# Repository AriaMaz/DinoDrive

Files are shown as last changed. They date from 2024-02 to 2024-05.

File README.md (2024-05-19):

# DinoDrive

<a href="https://code.engineering.queensu.ca/mren303_w2024/section003_group10_dinodrive/-/blob/main/README.md">
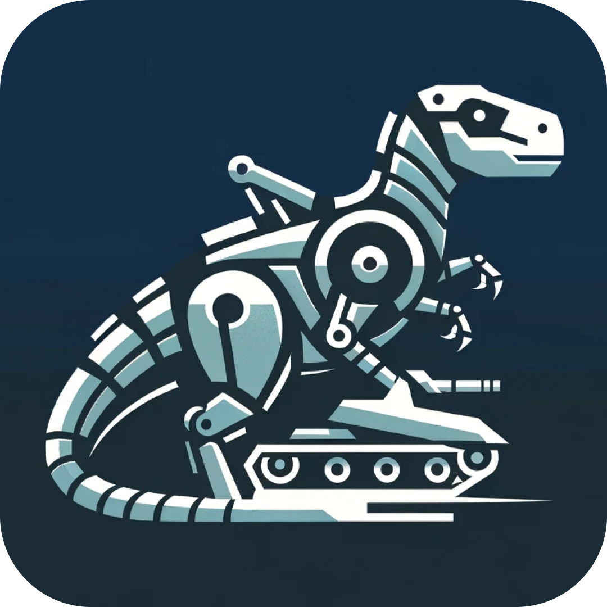
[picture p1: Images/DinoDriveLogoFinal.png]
    
</a>

</a>

Aria Maz <br>
Daniel Dubinko
<p><p>

Semi-autonomous robotic system developed for a competitive arena of navigation and object manipulation. <br>
– The robot operates in autonomous line following and manual remote controller modes.
<!-- <br> -->

<details>

<summary><h4>Setup</h4></summary>
To use this model, it is recommended to run the following command in your terminal based on your respective opperating system below to create a virtual environment and download the required package managerss, interpreters, and libraries.

#### MacOS

```html
<p>/bin/bash -c "$(curl -fsSL https://raw.githubusercontent.com/Homebrew/install/HEAD/install.sh)" && brew install python3 arduino && mkdir DinoDriveProject && cd DinoDriveProject && python3 -m venv DinoDriveEnv && source DinoDriveEnv/bin/activate && pip install opencv-python pyserial</p>
```

#### Windows

```html
<p>mkdir DinoDriveProject; cd DinoDriveProject; python -m venv DinoDriveEnv; .\DinoDriveEnv\Scripts\Activate; pip install opencv-python pyserial; choco install arduino</p>
```

#### Linux

```html
<p>sudo apt update && sudo apt install python3-venv python3-pip arduino && mkdir DinoDriveProject && cd DinoDriveProject && python3 -m venv DinoDriveEnv && source DinoDriveEnv/bin/activate && pip install opencv-python pyserial</p>
```
  </details>

<h3 align="center">Click on the image below to download the Report for this project</h3>
<div align="center">
    <a href="https://raw.githubusercontent.com/AriaMaz/DinoDrive/d2ab13fa74b5031a392671a74e04fc58c0d62a4a/MREN303FinalReport.pdf" download>
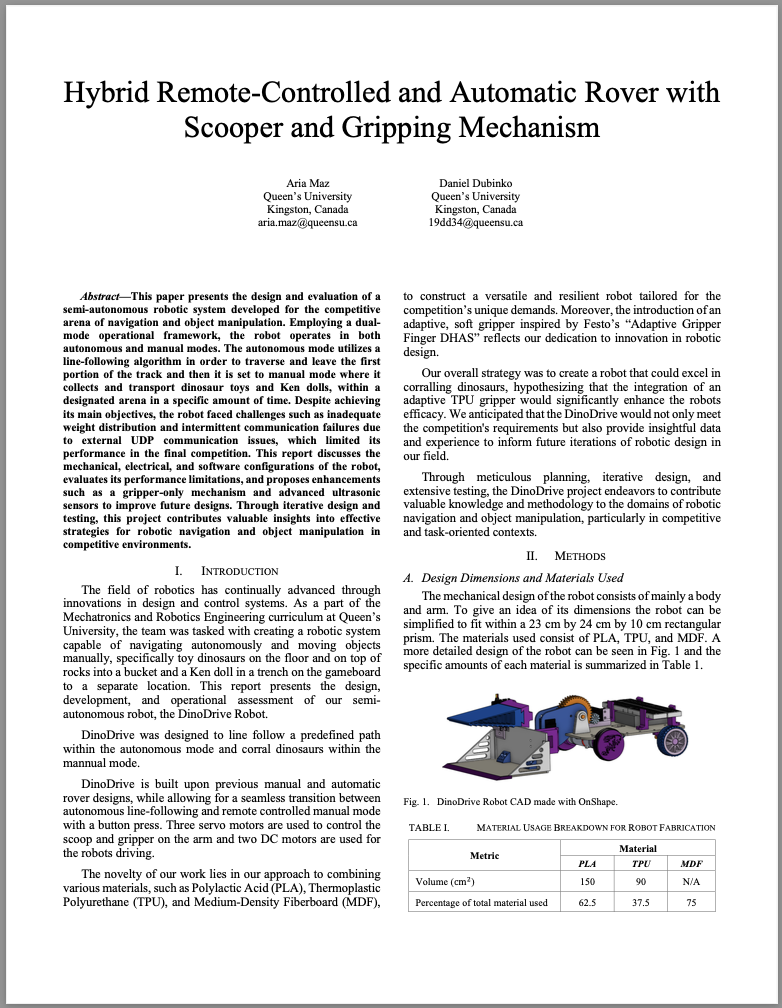
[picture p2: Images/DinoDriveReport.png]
PDF Preview
        
    </a>
</div>

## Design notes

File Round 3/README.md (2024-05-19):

## Goals for Round 3

1. Complete Round 3 Documentation
2. Design Electrical Schematic
3. Create Power Budget to ensure there suffucient power to power all the sensors
4. 3D Print and Assemble Mechanical Module
5. Scrum Planning for Round 3
6. Team Assessment and Peer Feedback
7. Manufacturing and Assembling Components 
8. Continously Keep Track of 3D Printed Volume

## DinoDrive Team Goals

1. Determine the amount of material needed to wrap the wheels in the rubber string
2. Create full proof code to control the servo motors and DC motors with the controller
3. Print the front wheels and laser cut the back wheels
4. CAD Model the line sensor and ultrasonic sensor mounts

## Backlog Items

1. Complete the CAD model for the base and main arm
2. Create gears for operating the arm and scoop
3. CAD the grippers for the front of the scoop

## Tasks to Reach Each Goal and Team Member Responsible
### Design Electrical Schematic
- **Tasks:**
  - Identify all components requiring electrical connections
  - Create a list of electrical specifications for each component
  - Plan the layout of the electrical schematic
  - Use appropriate software to design the electrical schematic

- **Team Members:**
  - Aria Maz

### Create Power Budget to ensure there is sufficient power to power all the sensors
- **Tasks:**
  - Determine the power requirements for each component
  - Calculate the total power consumption
  - Compare the total power consumption with the given battery pack

- **Team Member:**
  - Aria Maz

### 3D Print and Assemble Mechanical Module
- **Tasks:**
  - Review and finalize the 3D models for mechanical components
  - Assemble the printed components into the mechanical module
  - Inspect the assembled module for functionality and structural integrity

### Scrum Planning
- **Tasks:**
  - Review the progress of the project from the previous round
  - Identify and prioritize tasks for the upcoming round
  - Assign responsibilities to team members
  - Conduct a planning meeting with the Scrum team

- **Team Members:**
  - Daniel Dubinko
  - Aria Maz

### Team Assessment and Peer Feedback
- **Tasks:**
  - Dicuss goal progression and healthy, fact-driven conflict and ways to imporve them. 
  - Dicuss team commincation and focus and how to impove them
  - Sumarize findings in the correct file

- **Team Members:**
  - Daniel Dubinko
  - Aria Maz

###  Manufacturing and Assembling Components
- **Tasks:**
  - Convert 3D CAD models into STL files for 3D printing
  - Track the 3D print volume
  - Convert 3D CAD models into SVG files for laser cutting

- **Team Members:**
  - Daniel Dubinko

### Determine the Amount of Material Needed to Wrap the Wheels in the Rubber String
- **Tasks:**
  - Measure the circumference of each wheel
  - Calculate the required length of rubber string for each wheel
  - Cut the rubber string

- **Team Member:**
  - Daniel Dubinko

### Create foolproof code to control the servo motors and DC motors with the controller
- **Tasks:**
  - Develop a control algorithm for servo motors and DC motors
  - Write and test the code for motor control
  - Implement error handling and fail-safe mechanisms in the code
  - Document the code for future reference

- **Team Member:**
  - Aria Maz

### Create Gears for Operating the Arm and Scoop
- **Tasks:**
  - Design gears based on the required specifications.
  - 3D print gears for manufacturing.
  - Assemble gears.

- **Team Member:**
  - Daniel Dubinko

### CAD the Grippers for the Front of the Scoop
- **Tasks:**
  - Utilize CAD software (Onshape) to design grippers for the scoop.
  - Ensure the gripper design is compatible with the overall system.
  - CAD grip attachments to the servo.

- **Team Member:**
  - Daniel Dubinko

### Complete the CAD Model for the Base and Main Arm
- **Tasks:**
  - Utilize CAD software to create a detailed model of the base and main arm.
  - Ensure accuracy and compatibility with other components.
  - Review and finalize the CAD model.

- **Team Member:**
  - Daniel Dubinko

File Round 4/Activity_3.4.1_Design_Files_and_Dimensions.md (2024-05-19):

# Design Files Round 4
The design files can be found in **STL Files** Folder, and the **Laser Cutting Files** Folder, including dimensions of every part printed or cut. 

The design files include the STL Files for 3D printing, the Laser cutting files for all the MDF components and Measurements for all the components. 

**Total**: 245806 mm^3
**PLA Parts Printed**: 100,000 mm^3
**TPU Parts Printed**: 0 mm^3

**Material Left**: 145806 mm^3

*specific part volumes will be given in the later dates

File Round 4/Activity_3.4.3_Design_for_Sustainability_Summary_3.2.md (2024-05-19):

# Design For Sustainability

After discussing the various financial and environmental considerations in the fabrication and deployment of the robotic system within our team, we came to the conclusion that some of the approaches for sustainability relate to our current design process within our robots, such as using our code to achieve energy efficiency. 

Some approaches we take relate to our robot design, such as prioritizing more sustainable filaments and rechargeable batteries. We plan to add some conditions so that specific devices on the robot run only when needed so that the standby power consumption is significantly lower than when the robot is running all its sensors and actuators.

https://all3dp.com/2/best-sustainable-eco-friendly-biodegradable-3d-printer-filaments/

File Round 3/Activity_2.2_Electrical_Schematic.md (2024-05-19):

# Electrical Schematic

electrical subsystem
<strong>Figure 1:</strong> Physical electrical subsystem for DinoDrive robot.

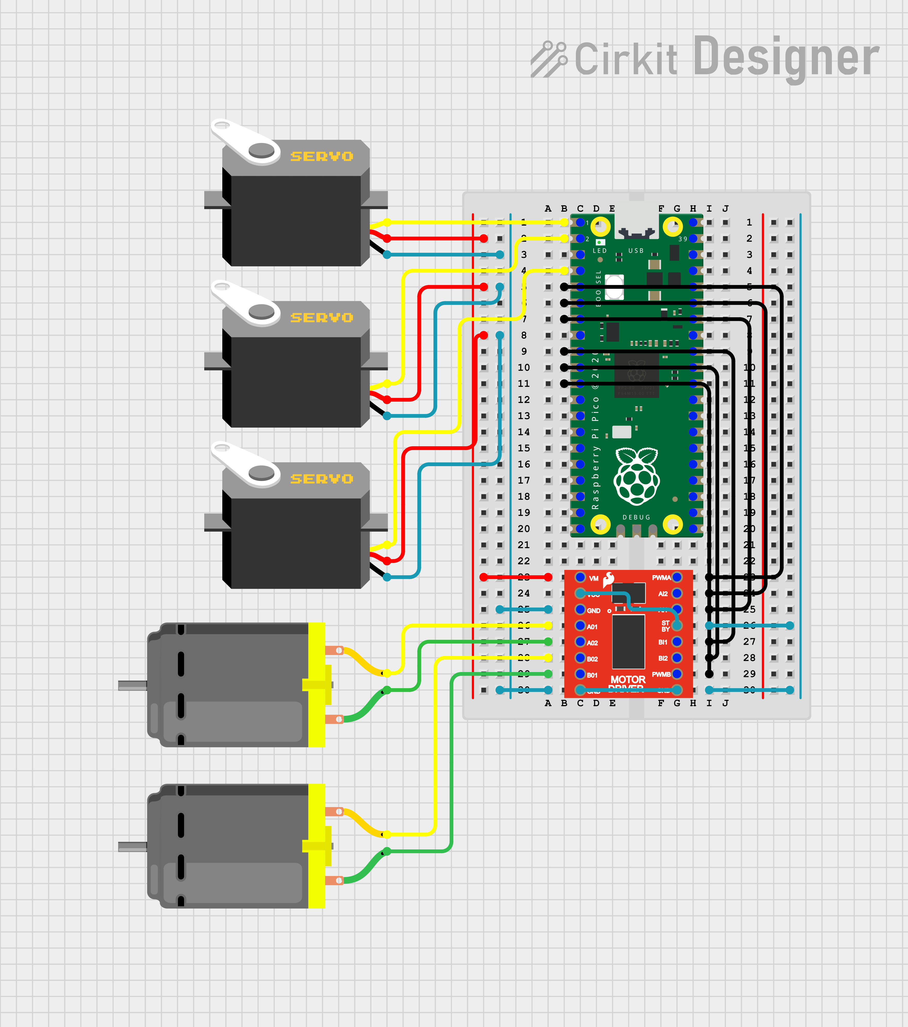
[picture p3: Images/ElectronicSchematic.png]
electrical schematic

<strong>Figure 2:</strong> Electrical schematic for DinoDrive robot.

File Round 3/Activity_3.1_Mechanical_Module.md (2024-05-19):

# Mechanical Module
## DC Motor and Back Wheel Attachment
The mechanical module chosen for display is the motor and wheel attachment to the main casing. The main casing and back wheel will be made out of carboard for display purposes until the laser cut parts can be obtained. 

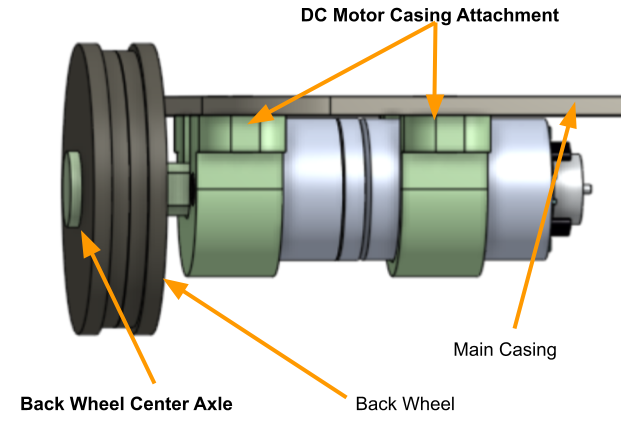
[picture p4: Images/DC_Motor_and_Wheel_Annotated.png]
<br>
**Figure 1:** DC Motor and Wheel attachment to the main casing.

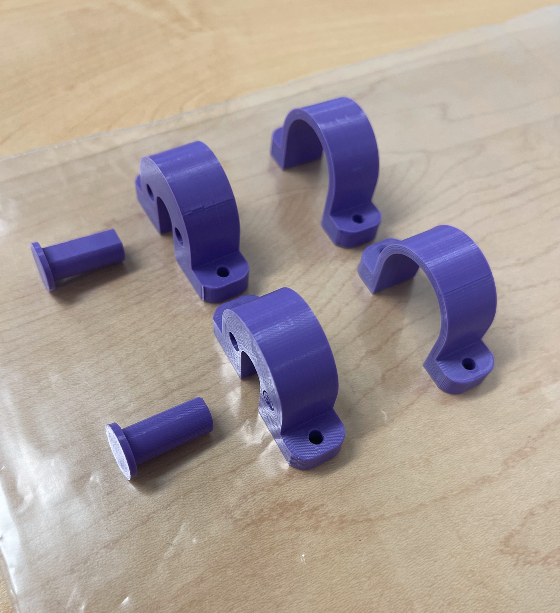
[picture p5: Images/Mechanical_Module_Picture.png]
<br>
**Figure 2:** DC Motor and Wheel 3D Printed Part.

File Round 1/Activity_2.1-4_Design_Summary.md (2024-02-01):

# Overarching Design Problem 

 1. Press the button, if the button press is not feasible then return to line following
    - leave the initial starting position using ultrasonic sensors by comparing the distance of all three sides. 
       - add PID to have precise movement during ultrasonic sensing
    - use the ultrasoninc sensors to align the robot in a way to press the button
    - set the grabbing/scooping portion of robot aligned at a predetermined height 
    - have back up line following code in case of any ultrasoninc sensor fails.
    
 2. Be able to enter through the door
    - realign the robot using the ultra sonic sensors and hard coded time to be able to enter through the door. 
    - since the ultrasonic sensors will be on the right, left, and front side have a max distance for the front side so the robot does not crash into the back wall

 3. Grab all the dinosaurs and place them into the black bucket
    - drive the robot using the Logitech Controller
    - knock off dinosaurs from the rocks or carefully grab them
    - grab each dinosaur separately and put them one by one into the bucket or push the dinosaurs together and scoop them into the bucket

 4. Ride up the ramp
    - ensure the robot does not bottom out when moving up the ramp
    - ensure the robot does not fall backwards comming up the ramp
    - ensure the robot does not get caught on the edge of the ramp

 5. Grab Ken 
    - grab or scoop Ken lighlty
    - raise him out of the ditch and continue down the ramp 
    - add fine steering control to make sure that Ken does not hit anything on any part of the journey

 6. Slowly take Ken to the helipad 
    - move fast enough to save time but slow enough to ensure the ride is smooth for Ken

# Constraints

1. 3D Printing Material
   - not exceeding the allowed amount

2. Time 
   - time is not being graded but a robot should not take too long to complete a task because that would be a waste of resources

3. Motors
   - only 3 servo motors and 2 DC motors are given. 

4. No Navigation Sensors Given (ex. LiDAR, Camera)
   - only ultrasonic sensors can be used for guidance 

5. Can Only Use Kit Materials
   - no other materials can be added 

6. Batteries Charge in 10 Hours so for iteration purposes the the back up batteries should always be charging

7. Batteries Output 4.8 volts when the DC motors require around 6V

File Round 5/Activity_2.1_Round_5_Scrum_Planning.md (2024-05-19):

# Goals for Round 5
1. Complete Round 5 Documentation
- Activity 2.1 (Aria Maz)
- Activity 2.3.3 (Aria Maz)
- Activity 4.3.1 (Daniel Dubinko)
- Activity 4.3.2 (Aria Maz)
2. Team Health Assessment and Peer Feedback
- Complete and reflect on feedback (Aria Maz and Daniel Dubinko)
3. Peer and Self-Assessment Surveys
- Conduct surveys and reflect on feedback (Aria Maz and Daniel Dubinko)
4. Update design files (Daniel Dubinko)
- Include a place to fit in the fail-safe line following the sensor on the CAD
5. Continuously Keep Track of 3D Printed Volume (Daniel Dubinko)
- Update [PLA](../STL_Files/PLA) and [TPU](../STL_Files/TPU) files in the [STL files](../STL_Files) (Daniel Dubinko).
6. Implement Autonomous mode
- Note: the main .ino script for running the robot should include code for the robot to execute during autonomous mode
- Milestones include demonstrating that the robot can run autonomously (Aria Maz).
  - Only need to demonstrate that we have programmed the robot to operate autonomously. Still, the algorithm does not have to be complete or successfully be able to exit the gameboard doors.
7. Prototype Testing
- Conduct tests on the gameboard and continuously iterate design (Aria Maz and Daniel Dubinko)

# DinoDrive Team Goals
1. Begin testing (Aria Maz and Daniel Dubinko)
- After finalizing the robot, begin practicing and  conduct a competition to see who is better at controlling the robot 
  - This will determine who will control it during the competition.

# Backlog Items
1. Update the CAD 
- Include ultrasonic Sensor Attachment and Line Sensor (Daniel Dubinko)

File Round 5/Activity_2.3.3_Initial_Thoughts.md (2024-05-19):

The team learnt that the scoop/claw to pick up Ken didn't generate enough torque to even move itself. Whilst the team had done rough back-of-the-envelope calculations for torque calculations the team failed to consider specifics such as the center of the mass of the claw with ken on it and its distance from the motors rotational Axis. The team decided to fix/improve the design by reducing the distance of the COM of the claw from the rotational axis of the servo motor and adding a 1:2 gear ratio since the full range of 180 degrees of motion is not necessary for our design and therefore can be sacrificed for the extra torque. Ideas generated to solve our low torque issue were inspired by the link below.

https://datamyte.com/blog/how-to-increase-motor-torque/#:~:text=By%20ensuring%20all%20moving%20parts,RPM%2C%20linearly%20increasing%20the%20torque.

However, the driving portion of the robot worked flawlessly, being able to complete sharp turns and climb the ramp with great traction and little to no skidding.

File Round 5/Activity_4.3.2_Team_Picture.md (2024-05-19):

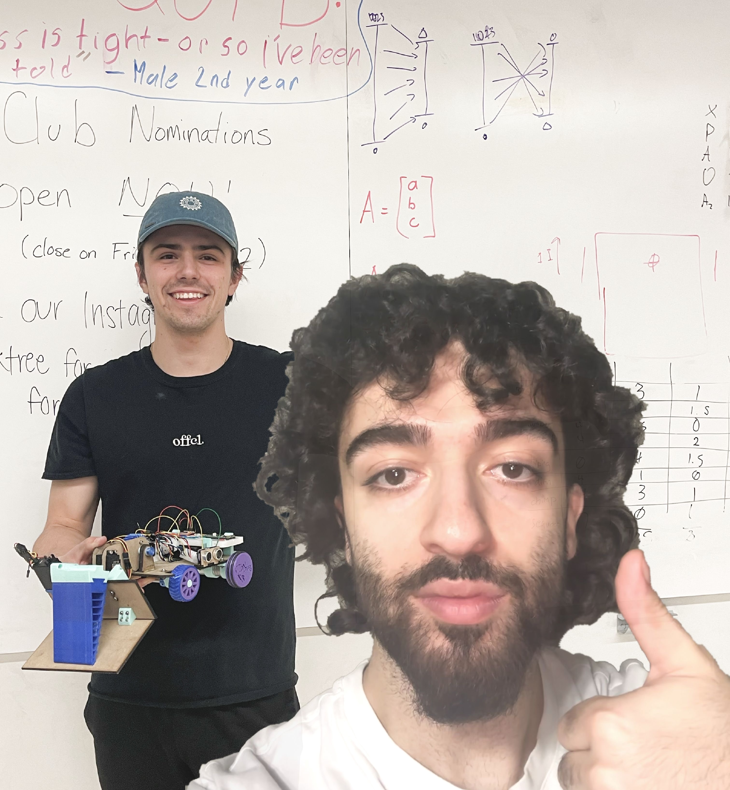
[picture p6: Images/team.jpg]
Team Photo
<br>
**Figure 1:** Picture of all team members (Aria Maz and Daniel Dubinko) with the current DinoDrive robot prototype.

We do consent to the use of our picture! :)

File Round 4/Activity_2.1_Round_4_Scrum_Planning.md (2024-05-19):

# Goals for Round 4

1. Complete Round 4 Documentation
2. Assemble Robot Chassis
3. Summarize Environmental Paragraph 
4. Scrum Planning for Round 3
6. Team Assessment and Peer Feedback Summary and 
7. Manufacturing and Assembling Components 
8. Continously Keep Track of 3D Printed Volume
9. Battery Monitoring Code
10. Work Plan Reflection and Module Integration
11. Document Initial Thoughts of the Robot

# DinoDrive Team Goals

1. Determine the amount of material needed to wrap the wheels in the rubber string
2. Create full proof code to control the servo motors and DC motors with the controller
3. Add Support to Crane 
4. Print and laser cut all the parts

# Backlog Items

1. Complete the CAD for ultrasonic Sensor Attachment and Line Sensor

## Goal 1: Complete Round 4 Documentation
- **Tasks:**
  - Collect information on all activities conducted during Round 4
  - Summarize key points and outcomes
  - Ensure all relevant documentation is organized and accessible

- **Team Members:**
  - Daniel Dubinko, Aria Maz

## Goal 2: Assemble Robot Chassis

- **Tasks:**
  - Gather all necessary components for the robot chassis
  - Follow the assembly instructions or guidelines
  - Double-check all connections and ensure a secure assembly

- **Team Members:**
  - Daniel Dubinko, Aria Maz

## Goal 3: Summarize Environmental Paragraph

- **Tasks:**
  - Analyze the environmental paragraph content
  - Extract key points and relevant information
  - Compile a concise summary of the paragraph

- **Team Members:**
  - Daniel Dubinko

## Goal 5: Team Assessment and Peer Feedback Summary

- **Tasks:**
  - Collect individual team assessments and peer feedback
  - Summarize common themes and notable points
  - Prepare a comprehensive summary report

- **Team Members:**
  - Aria Maz

## Goal 6: Manufacturing and Assembling Components

- **Tasks:**
  - Ensure all required components are manufactured
  - Assemble manufactured components into the robot structure
  - Conduct quality checks on assembled components

- **Team Members:**
  - Daniel Dubinko, Aria Maz

## Goal 7: Continuously Keep Track of 3D Printed Volume

- **Tasks:**
  - Monitor the ongoing 3D printing progress
  - Keep track of the volume of 3D printed materials
  - Ensure a sufficient supply of printing materials

- **Team Members:**
  - Daniel Dubinko

## Goal 8: Battery Monitoring Code

- **Tasks:**
  - Research and identify suitable code for battery monitoring
  - Implement and test the code on the robot's microcontroller
  - Ensure accurate and real-time monitoring of battery status

- **Team Members:**
  - Aria Maz

## Goal 9: Work Plan Reflection and Module Integration

- **Tasks:**
  - Reflect on the effectiveness of the current work plan
  - Identify areas for improvement and optimization
  - Plan the integration of different modules for seamless functionality

- **Team Members:**
  - Daniel Dubinko

## Goal 10: Document Initial Thoughts of the Robot

- **Tasks:**
  - Gather thoughts and insights on the robot's design and functionality
  - Document initial impressions and expectations
  - Ensure clarity and coherence in the documentation

- **Team Members:**
  - Daniel Dubinko, Aria Maz

## DinoDrive Team Goals

### Goal 1: Determine the amount of material needed to wrap the wheels in the rubber string

- **Tasks:**
  - Measure wheel dimensions and surface area
  - Calculate the required amount of rubber string for wrapping
  - Consider extra material for contingencies

- **Team Members:**
  - Daniel Dubinko

### Goal 2: Create foolproof code to control the servo motors and DC motors with the controller

- **Tasks:**
  - Research and implement robust code for servo and DC motor control
  - Test the code thoroughly under various scenarios
  - Ensure compatibility with the chosen controller

- **Team Members:**
  - Daniel Dubinko, Aria Maz

### Goal 3: Add Support to Crane

- **Tasks:**
  - Design and implement additional support for the crane mechanism
  - Ensure structural integrity and compatibility with the existing robot structure
  - Test the crane functionality with the added support

- **Team Members:**
  - Daniel Dubinko

### Goal 4: Print and laser cut all the parts

- **Tasks:**
  - Organize the printing and laser cutting of all required parts
  - Ensure accurate dimensions and quality of the printed and cut parts
  - Coordinate with the manufacturing team for timely production

- **Team Members:**
  - Daniel Dubinko

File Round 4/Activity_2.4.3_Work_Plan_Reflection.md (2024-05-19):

## Work Plan Reflection

The team is on track for most of the deliverables. The vision for our prototype is nearing completion; we have determined the final amount of material we will need and created and printed a complete CAD model for the robot with material to spare. The team has promptly met all key deliverables on time and plans to continue doing so.

The assigned tasks between team members are fair and reflect the required workload. Sometimes, either team member is overwhelmed, and we are always ready to lend a helping hand. The project is still within the specified budget in that we will need any extra filament, plc, material, or devices other than adhesives.

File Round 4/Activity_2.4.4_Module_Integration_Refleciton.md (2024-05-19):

# Module Integration Reflection 

## Module Picture
<br>
**Figure 1:** Current Robot Module.

## Module Description 
### Robot Performance 
The module's performance was generally satisfactory. However, we encountered an issue with the motors initially, as they failed to operate due to pressure from the front section. After loosening the screws, the motors functioned as intended. Additionally, we identified the need to refine the code for smoother driving in various directions. On a positive note, the breadboard integration was seamless, and we plan to enhance the front wheels by incorporating TPU tires.

### Future Iteration
In our upcoming iteration, we plan to integrate a robot crane and scoop, as showcased in the **Current Prototype** file. Looking ahead, to other concepts we envision implementing a centrally powered wheel for improved control. Furthermore, the inclusion of omni wheels is under consideration to further enhance maneuverability. However, for the current scope of the problem the current design will suffice.

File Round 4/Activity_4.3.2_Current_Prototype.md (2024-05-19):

# Current Robot Prototype
*missing ultrasonic sensors and line following sensor. 

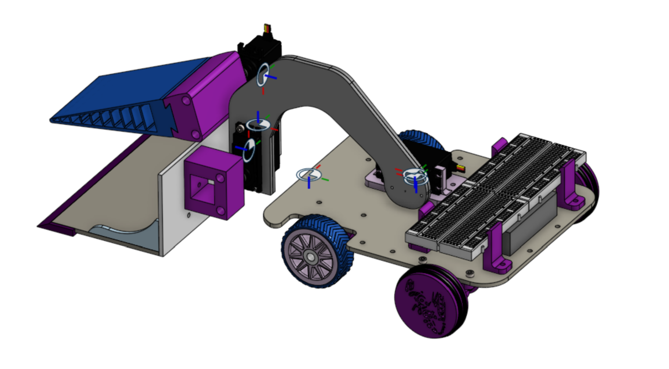
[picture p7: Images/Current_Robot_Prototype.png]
<br>
**Figure 1:** Current Robot Prototype.

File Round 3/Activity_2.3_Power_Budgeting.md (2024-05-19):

**Power Budget**
|Component|Nominal Voltage (V)|Nominal Current Draw (A)|“worst-case” Current Draw (A)|Nominal Power (W)| “worst-case” Power (W)|
| --- | --- | -- | -- | --- | --- |
|Servo Motor 1 |4.8-6.0 |0.15|0.15|0.72 |0.9  |
|Servo Motor 2 |4.8-6.0 |0.15|0.15|0.72 |0.9  |
|Servo Motor 3 |4.8-6.0 |0.15|0.15|0.72 |0.9  |
|DC Motor 1 |6 |0.13|3.2 |0.78 |19.2 |
|DC Motor 2 |6 |0.13|3.2 |0.78 |19.2 |
|Motor Driver |5.5 |1.2 |1.2 |6.6  |6.6  |
|Raspberry Pi Pico W|1.8-5.5 |0.5 |0.9 |2.75 |4.95 |
|**Total**|**33.7-330**|**2.41**|**8.55**|**11.22**|**52.65**|

  <strong>Figure 1:</strong> Power budget for DinoDrive robot.

- *Battery pack will approximatley last about 44 miniutes to 2 hours and 56 miniutes given a full charge*
<br>
<br>

**Servo Motors:**
https://media.digikey.com/pdf/data%20sheets/dfrobot%20pdfs/ser0002_web.pdf

**DC Motors:** https://www.dfrobot.com/product-1617.html

**Battery:** https://www.duracell.com/wp-content/uploads/2018/12/AA2500HP-PREMIUM-v1.0.pdf

**Motor Driver:** https://www.sparkfun.com/datasheets/Robotics/TB6612FNG.pdf

**Raspberry Pi Pico:** https://datasheets.raspberrypi.com/picow/pico-w-datasheet.pdf

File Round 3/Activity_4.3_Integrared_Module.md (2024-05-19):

# Integrated Module
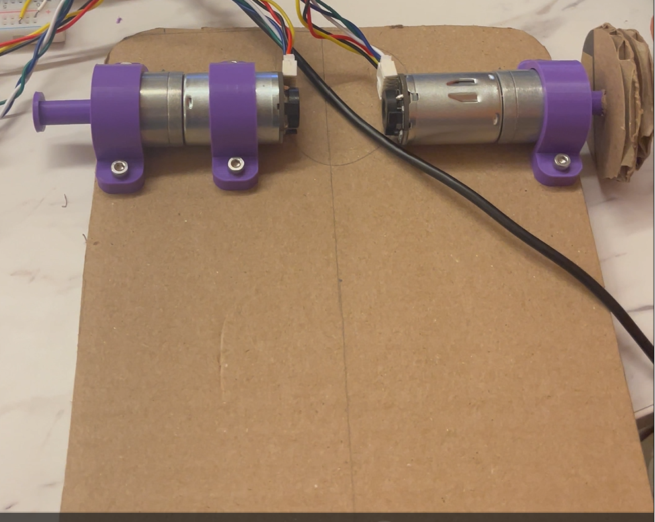
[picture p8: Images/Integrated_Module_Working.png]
<br>
**Figure 1:** DC Motor and Wheel attachment to the main casing in practice.

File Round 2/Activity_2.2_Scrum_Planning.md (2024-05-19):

## Goals for Round 2

1. Complete Round 2 Documentation
2. Turn the servo motor 180 degrees and back
3. Health and Safety Update
4. Cardboard Prototype
5. Scrum Planning
6. FRDPARRC Table
7. DC Motor Spinning
8. Ultrasonic Reading and Table

## DinoDrive Team Goals

1. Determine the amount of material needed to wrap the wheels in the rubber string
2. Create code to control the servo motors and DC motors with the controller
3. Create gears for operating the arm and scoop
4. CAD the grippers for the front of the scoop
5. Decide on front wheels

## Backlog Items

1. Update the Cardboard Prototype
2. Complete the CAD model for the base and main arm
3. Decide on wheel design for front wheels

## Tasks to Reach Each Goal and Team Member Responsible
### Complete Round 2 Documentation
- **Tasks:**
  - Review and compile individual contributions.
  - Ensure all required documentation elements are covered.
  - Edit and format the document for consistency.

- **Team Members:**
  - Daniel Dubinko
  - Aria Maz

### Turn the Servo Motor 180 Degrees and Back
- **Tasks:**
  - Read the servo motor specifications and control methods on OnQ.
  - Write code for precise servo motor movement.
  - Test servo motor movement in both directions.

- **Team Member:**
  - Aria Maz

### Health and Safety Update
- **Tasks:**
  - Review and update safety protocols based on project requirements.
  - Communicate updated safety information to the team.
  - Ensure adherence to safety standards during the project.

- **Team Members:**
  - Daniel Dubinko
  - Aria Maz

### Cardboard Prototype Build
- **Tasks:**
  - Gather required cardboard materials.
  - Cut and assemble cardboard components according to the design.
  - Convert the measurements of the prototype to CAD.
  - Incorporate feedback and modifications to the existing cardboard prototype.
  - Test and validate the updated cardboard prototype.

- **Team Member:**
  - Daniel Dubinko

### Scrum Planning
- **Tasks:**
  - Create tasks and subtasks for each goal.
  - Throw all ideas onto Notion and then organize it throughout the design process.
  - Create and continuously adjust a work plan to stay on track.

- **Team Members:**
  - Daniel Dubinko
  - Aria Maz

### FRDPARRC Table
- **Tasks:**
  - Collect and organize data relevant to FRDPARRC components.
  - Create a structured table presenting FRDPARRC information.

- **Team Members:**
  - Daniel Dubinko
  - Aria Maz

### DC Motor Spinning
- **Tasks:**
  - Read OnQ for suitable methods for controlling DC motor rotation.
  - Develop and test code for spinning the DC motor.

- **Team Members:**
  - Daniel Dubinko
  - Aria Maz

### Ultrasonic Reading and Table
- **Tasks:**
  - Read ultrasonic sensor specifications and data reading methods.
  - Develop code for accurate ultrasonic data reading.
  - Create a table to organize and present ultrasonic sensor data.

- **Team Members:**
  - Daniel Dubinko
  - Aria Maz

### Determine the Amount of Material Needed to Wrap the Wheels in the Rubber String
- **Tasks:**
  - Measure the circumference of the wheels.
  - Find the length and thickness of rubber string.
  - Determine how many revolutions of string are possible with the given material.

- **Team Member:**
  - Daniel Dubinko

### Create Code to Control the Servo Motors and DC Motors with the Controller
- **Tasks:**
  - Research and select a suitable controller for servo and DC motors.
  - Develop code for integrating the controller with motors.
  - Test and debug the code for precise motor control.

- **Team Member:**
  - Aria Maz

### Create Gears for Operating the Arm and Scoop
- **Tasks:**
  - Design gears based on the required specifications.
  - 3D print gears for manufacturing.
  - Assemble gears.

- **Team Member:**
  - Daniel Dubinko

### CAD the Grippers for the Front of the Scoop
- **Tasks:**
  - Utilize CAD software (Onshape) to design grippers for the scoop.
  - Ensure the gripper design is compatible with the overall system.
  - CAD grip attachments to the servo.

- **Team Member:**
  - Daniel Dubinko

### Complete the CAD Model for the Base and Main Arm
- **Tasks:**
  - Utilize CAD software to create a detailed model of the base and main arm.
  - Ensure accuracy and compatibility with other components.
  - Review and finalize the CAD model.

- **Team Member:**
  - Daniel Dubinko

### Decide on Wheel Design for Front Wheels
- **Tasks:**
  - Research and evaluate various wheel designs.
  - Consider factors such as traction, durability, and size.
  - Collaborate with the team to make an informed decision.

- **Team Member:**
  - Daniel Dubinko

### Decide on Wheel Design for Back Wheels
- **Tasks:**
  - Apply the same process as deciding on the front wheel design.
  - Ensure consistency and compatibility with the overall system.

- **Team Member:**
  - Daniel Dubinko

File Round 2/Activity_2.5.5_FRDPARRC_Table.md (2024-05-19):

| | Functional Requirements | Design Parameters | Analysis | References | Risk | Countermessures |
| --- | --- | --- | --- | --- | --- | --- |
| **Strategy** | Corralling dinosaurs | Plow and dump dinosaurs on the floor and pick up / drop off dinosaurs on rocks into the cage | Speed/time required to collect and dump dinosaurs | Existing robot arms and dumpers | Collection or dumping is too slow | A lightweight and therefore quick robot|
| **Concept** | Increasing score/points| 1.Plow to shovel dinasours on ground <br> 2.Robotic arm/gripper to pick up dinosaurs <br> 3.Dumpable bucket on board to hold and dump collected dinosaurs (Cardboard Prototype)| 1. Maximum dinosaurs able to be plowed due to power restrictions <br> 2. Maximum dinosaurs can be held due to COM and torque restrictions <br> 3. Geometric | 1. Datasheet for servo and motor <br> 2. Physics <br> 3. Physics| 1. All dinosaurs together are too heavy <br> 2. The robot is too light and torque from the weight of dinosaurs tips over the robot due to COM <br> 3. Dinosaurs get stuck/wedged between the edge of the cage and bucket| 1. Take more than 1 trip to plow dinosaurs <br> 2. Optimize COM by moving parts and increase the length/width of the robot base <br> 3. Drop the dinosaurs into the bucket from the top of the ramp so cage walls are not in the way (this also puts us in the right place to pick up Ken right after)<br>|

**Reference:**
Wu, A. (2024) ‘MREN303_W2024_Week2_Lecture3’, onQ, 7 February.

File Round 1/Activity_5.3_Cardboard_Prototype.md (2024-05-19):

# CardBoard Prototype

The prototype primarily focuses on the robot's body as seen in Figure 1. Its purpose is to establish overall measurements for seamless integration into 3D modeling. A specific objective we aim to gauge is the optimal angle for the scooper/arm to rest on the body, enabling it to reach Ken while also elevating to reach the dinosaurs. Another objective we hope to ascertain is the overall size of the body, ensuring adequate space for all components, and determine the placement of the ultrasonic sensor and line following sensor.

<p align="center">
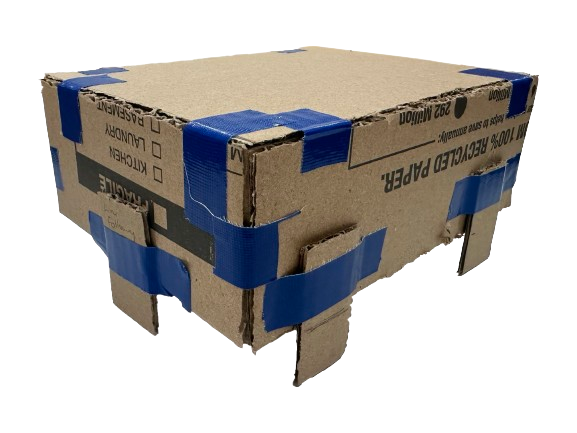
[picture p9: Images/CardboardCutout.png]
Box
  
  <br>
  <strong>Figure 1:</strong> Cardboard Prototype (so far).
</p>

# Reflection on Our Cardboard Prototype

## What did we set out to do?
- Determine the placement of the line sensor
- Determine maximum length and width of the robot base and wheels
- Decide on the location and size of the arm and scoop
- Determine the location of the DC motors powering the wheels. 
- Location of the ultrasonic sensors

## What did we learn from the prototype?
**Line Sensor**
- The line sensor cannot be positioned in the middle of the front of the robot base because it will collide with the ramp on the way up or down.

**Base and Wheels**
- Since the arena door measures 25 cm, the robot's width must be smaller than that to ensure easy passage without a snug fit. The maximum length is limited to 22 cm to fit within the 23 cm space between the ramp and Ken's placement hole.

**Arm and Scoop**
- Placing the arm base at the front of the robot ensures ample space for electronic components at the rear. The scoop, located at the front, can exceed the robot's width as it has the capability to be lifted higher than the arena door.

**DC Motors**
- The DC motors are quite lengthy and occupy a significant amount of space on the top of the robot base.

**Ultrasonic Sensors**
- An ultrasonic sensor cannot be positioned at the front of the robot because the scoop and arm will obstruct its placement.

## What changes did we make based on our the insights?

**Line Sensor**
- Positioning the line sensor at the rear of the robot is crucial. Placing it at the back ensures that it won't encounter obstacles, such as the ramp, during ascents or descents. This strategic placement allows the robot to consistently sense the line throughout the entire line-following procedure.

**Base and Wheels**
- The robot's width of 17 cm was chosen to accommodate the 25 cm arena door. The length of the base was chosen to be 20 cm to ensure optimal space for movement on the ramp.

**Arm and Scoop**
- The arm and scoop will be wider than the robot and raised when the robot is entering the arena door. The arm base will be secured to the front part of the robot base.

**DC Motors**
- The DC motors will be placed on the bottom of the base to allow for more room for Raspberry Pi, breadboard, and other electronic components.

**Ultrasonic Sensors**
- The three ultrasonic sensors will be placed with two at each side and one at the back.

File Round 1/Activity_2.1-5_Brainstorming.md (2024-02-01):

# Brainstorming Design Ideas
Ideas were generated by seperating the project into subsections. 

The subsections are the arm/gripper, the body and the driving mechanism (wheels). 

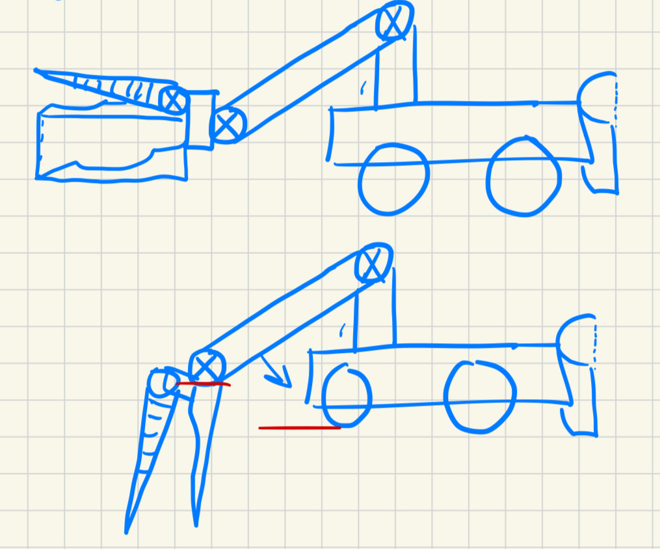
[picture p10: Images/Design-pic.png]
Risk Managment Rating


## Driving
 ### Idea 1 - Real Wheel Drive with Two Other Front Wheels
**Chosen**: We opted for rear-wheel drive with two freely spinning front wheels due to the constraint of having only two motors. This choice eliminates the need for a complex gear system required for four-wheel drive. Rear-wheel drive ensures good traction and stability, with the motors at the back helping balance the weight distribution. The two front wheels contribute extra stability, making this configuration the ideal choice for the project.

### Idea 2 - Two Wheel Drive with Castor Wheel
**Not Chosen**: A two-wheel drive with a caster wheel may provide agility, but it lacks both stability and control. The unpredictability of caster wheel driving, particularly at higher speeds, makes it unsuitable for our project. Additionally, the 3D printing of the caster wheel poses challenges, as 3D prints lack the smoothness required for the frictionless characteristics essential for effective caster wheel operation.

### Idea 3 - Two Wheel Drive with 3 Wheels on Each Side: 
**Not Chosen**: The driving force comes from the middle wheel on each side, with two freely spinning wheels on the left and right for stability. While this design is inherently stable and maintains relatively balanced weight if the crane isn't too heavy, it requires more 3D printing and uses additional material without significant added benefits in terms of stability and central rotation.

### Idea 4 - Tank Treads: 
**Not Chosen**: Tank treads provide excellent traction over various terrains, but they can be quite complex to design and implement. This is our favourite option and if we had more time and material then it would be an intersting design to iterate and create. We decided to focus our energy into the arm/gripper since it is the more complicated aspect of the project and is the deciding factor. 

## Arm/Gripper
### Idea 1 - Gripper + Scooper + Pusher Combo
**Chosen**: This combination provides a versatile solution. The gripper/scooper for grabbing either the dinosaurs or ken, a scooper for placing the the dinosaurs into the box. And a pusher wall at the back for pushing more then 1 dinosaur at a time. 
### Idea 2 - Gripper
**Not Chosen**: A gripper alone might be suitable for certain tasks but lacks the versatility offered by additional functionalities of the scopper and pusher. Also a pusher/scooper can move more than one dinosaur simultaneously which saves time.

### Idea 3 - Gripper + Scooper
**Not Chosen**: The pusher is easily implemented and can move multiple dinosaurs simultaneously without the unnecessary movement of a gripper or scooper. Its addition to the design incurs minimal time and material loss, while its removal compromises usability.

## The Body
### Idea 1 - Rectangular Prism
**Chosen**: We've chosen the Rectangular Prism for our robot's body due to its practicality, efficient use of space, and easy integration of components. The straightforward shape enhances stability and balance, crucial for optimal performance. Its simplicity streamlines the iteration process, making assembly and maintenance more manageable. Additionally, we'll allocate space in the front of the body for the arm and gripper.

### Idea 2 - Cylindrical Can Shape
**Not Chosen**: While a Cylindrical Can Shape might have visual appeal, the practical benefits of the Rectangular Prism, such as functionality, ease of assembly, increases building area and stability, make it the preferred choice for our group's robot body.

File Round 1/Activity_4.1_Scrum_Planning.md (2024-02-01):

The specific goals for this round are to enable communication between the Raspberry Pi Pico W and the Logitech F310 Wired Gamepad using an Arduino and Python script. In addition, a rough cardboard prototype should be started to get a better mechanical understanding of a specific module.
The team’s goal for this round is to get a basis for the Dino Drives design and strategy to win the challenge. To get closer to this objective 2 tasks with subtasks are described below. 

# 1.    Choose which objectives within competition details to prioritize (Aria)

## Timing
| Module | Time |
| --- | --- |
| Autonomous Mode | 30 Seconds |
| Manuel Mode | 30 Seconds |

## Scoring
| Action | Points |
| --- | --- |
| Exit gate autonomously using push button | 8 |
| Exit gate autonomously using line following | 4 |
| Dinosaurs corralled | Max 6 (scaled to number in corral)|
| Doll saved (from pit to helipad) | Max 6 (scaled to the accelerometer)|

- If the points between teams are equal, the winner completes the tasks in the least amount of time.

### Slow & Steady Wins the Race
Based on the scoring system it should be noted that completing the task in a short amount of time is only valuable when the points between the teams are equal. Among all the actions that can earn you points saving the doll with 6 points "scaled to the accelerometer," assuming the accelerometer is somewhat precise, it will be very rare for two teams to finish with the same amount of points. Therefore, trying to optimize the time it takes to complete actions should be the last priority and the design of the robot should focus on precision, accuracy, and stability over speed.

Corralling dinosaurs and saving the doll will be given an equal weighting in priority and the highest priority will be given to exiting the gate using the pushbutton since it is awarded the most points and seems to be the easiest to achieve.

# 2.    Determine constraints on size of robot (Aria & Daniel)
Multiple things limit the size of the robot so they are split into subtasks shown below.

### 2.1 - Dimensions of the board (Aria)
The robot must be a specific width to fit through the gate or a specific length to be able to easily stand on the platform above the ramp. These constraints are explored in more detail within the [Back of the Envelope Calculation File](https://code.engineering.queensu.ca/mren303_w2024/section003_group10_dinodrive/-/blob/main/Round1/Activity_4.4-4_Back-of-the-Envelope_Calculation.md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) within the [Round 1 Folder](https://code.engineering.queensu.ca/mren303_w2024/section003_group10_dinodrive/-/tree/main/Round1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).

### 2.2 - Volume consumed by the print (Daniel)
The robot must not use 3D print filament that consumes a volume greater than 11 in<sup>3</sup> which is 180.258 cm<sup>3</sup> in the metric system. Because ample planning will be conducted it will be assumed that no more than 1.5 times more filament than intended will be used (this estimate is on the higher end to play it safe) resulting from errors and changes in design. This leaves us with 120.172 cm<sup>3</sup>. This is a small amount of volume to work with so 3D printing will be used for the intracit pieces of the board such as the TPU Gripper we are creating seen below and other parts can be created using the much larger MDF Panel (23.5" x 11.75" - 1/8").

<p align="center">
  TPU Gripper
  <br>
  <strong>Figure 1:</strong> TPU Gripper
</p>

[1] “Adaptive gripper fingers,” YouTube, https://www.youtube.com/watch?v=jOc3e5O5OPM&ab_channel=FestoCanada (accessed Jan. 24, 2024). 

### 2.3 - Other (Daniel)
It is too early within the preliminary design to consider other constraints such as the maximum torque of the robotic arm supplied by the servo's since the goal is to get a basis for the design and to start doing torque calculations for the design for at least the arm of the robot should be completed.

Another constraint that may arise can be fine-tuning the COM of the robot such that when picking up the doll (the heaviest object required to be moved) the robot does not tip over from the weight of the arm and the additional weight of the doll, but again a design for the robot should be decided on before tackling this possible problem.

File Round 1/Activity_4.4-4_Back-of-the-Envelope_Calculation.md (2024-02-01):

To determine the constraints on the size of the robot, it is paramount to have an accurate model of the arena size. So, what are the dimensions of the arena, and how does this limit the robot's size?

## Assumptions
1. Other factors do not entirely control the size of the robot.
    - The maximum volume consumed by the prints.
    - The maximum torque of the robotic arm supplied by the servos (compared to the weight length of the arm itself).
    - Adjusting weight and COM such that the robot does not tip over from the weight of the arm and the additional weight of the doll (heaviest object required to be moved).

2. The robot's orientation is parallel to the walls, with the front-facing out of the starting position and towards the doll when climbing the ramp.

## Measurements & Calculations

The entire arena with all relevant dimensions is measured and displayed in Figure 1 below.

<p align="center">
  Arena
  <br>
  <strong>Figure 1:</strong> Scaled arena with relavant dimensions.
</p>

After analysis of the measurements, it was determined that the constraining distance for the width (W) of the robot is the width of the door (25 cm). The constraining distance for the length (L) of the robot is the distance between the highest point of the ramp and the edge of the pit where the doll lies closest to the ramp. This was calculated below to be 24 cm.

$42 cm - 18 cm = 24 cm$

## Take Aways
While these numbers work in theory, it is essential to note that we need to allow for tolerance in real life. Therefore, allowing for a 0.5 cm error on either side of the robot as the minimum tolerance we can realistically achieve, the final constraints for the maximum length and width of the robot are listed below.

$L = 23 cm$
<p>
$W = 24 cm$
<p>

While it may be possible to complete the task with these dimensions, the smaller the robot, the easier it will be to maneuver, and the less chance factors like the limit of 3D print volume will come into play.

 In addition, if any of the robot parts, such as the arm/claw, reach over the door or hang over the pit, these values would only apply to the robot's body as long as the robot COM is taken into consideration to avoid it tipping over.

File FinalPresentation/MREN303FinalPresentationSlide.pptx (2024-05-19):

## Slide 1

Dino Drive

Group 10: Aria Maz & Daniel Dubinko

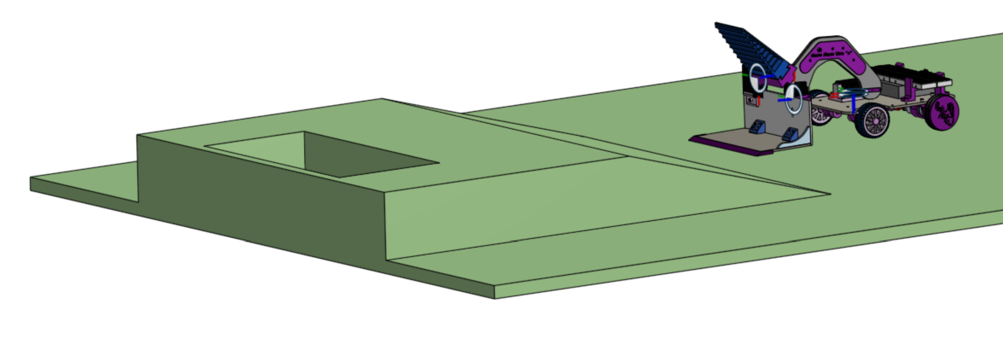
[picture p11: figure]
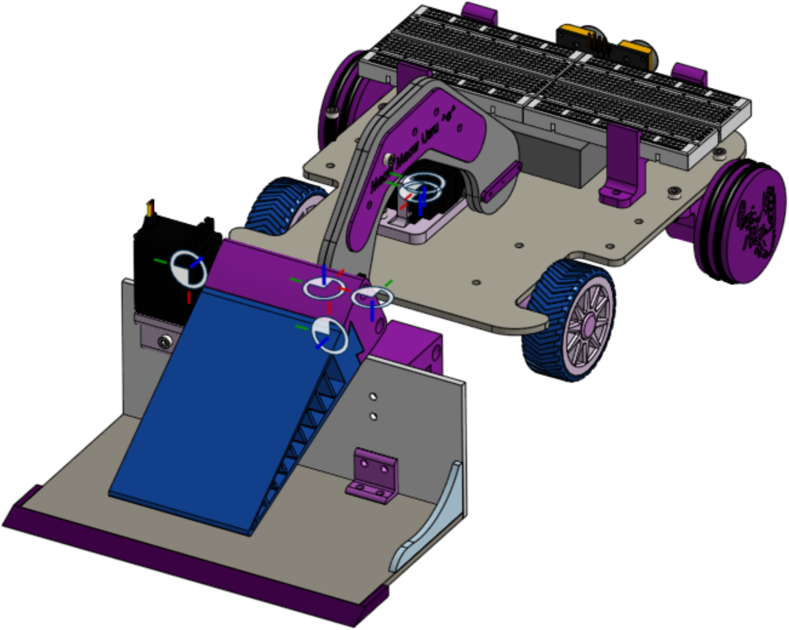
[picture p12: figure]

Servo 1

Servo 3

Servo 2

= PLA

= TPU

= MDF

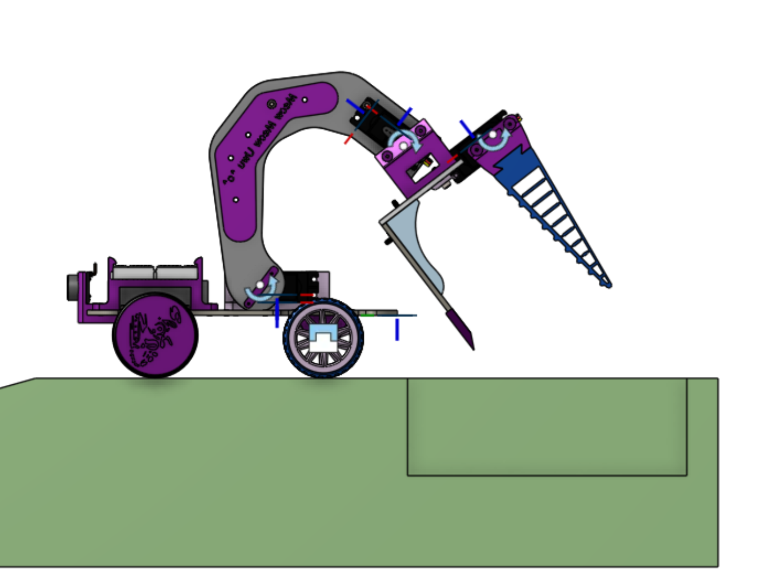
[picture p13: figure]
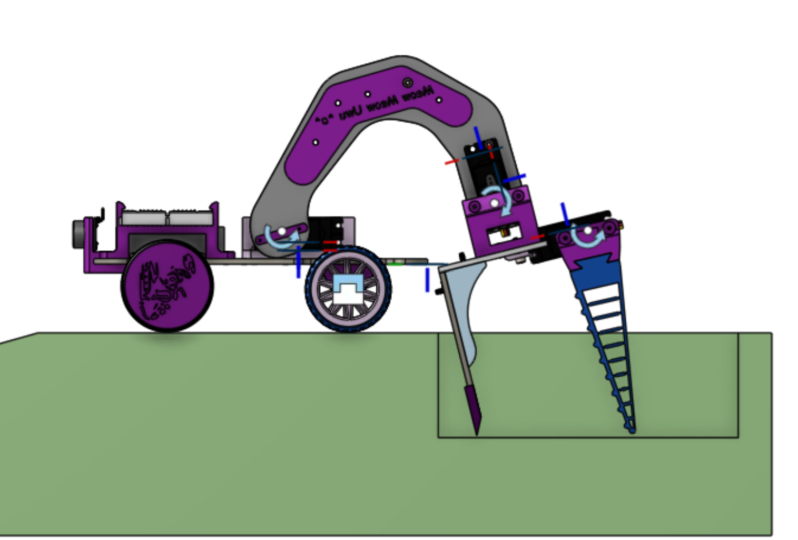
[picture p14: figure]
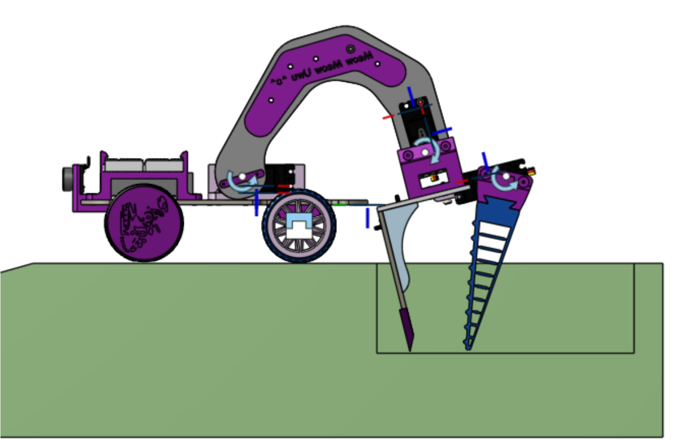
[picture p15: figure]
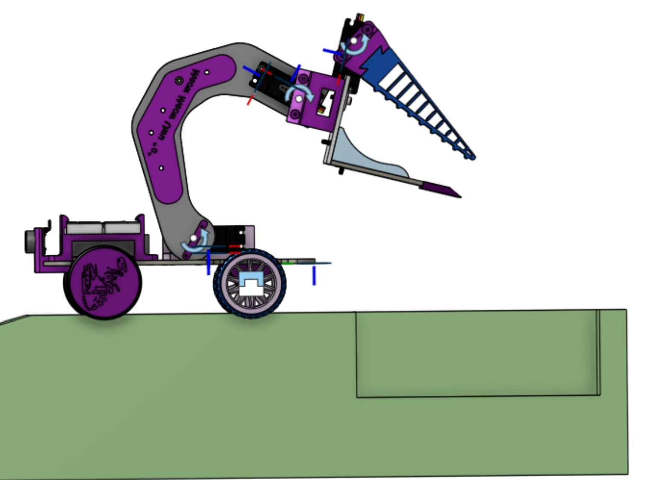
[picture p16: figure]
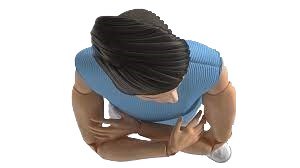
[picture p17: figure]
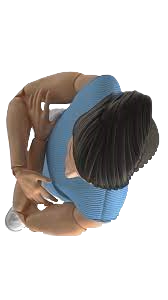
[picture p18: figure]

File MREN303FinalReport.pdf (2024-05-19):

# Hybrid Remote-Controlled and Automatic Rover with Scooper and Gripping Mechanism

Aria Maz
Queen’s University
Kingston, Canada
aria.maz@queensu.ca

Daniel Dubinko
Queen’s University
Kingston, Canada
19dd34@queensu.ca

Abstract—This paper presents the design and evaluation of a semi-autonomous robotic system developed for the competitive arena of navigation and object manipulation. Employing a dual-mode operational framework, the robot operates in both autonomous and manual modes. The autonomous mode utilizes a line-following algorithm in order to traverse and leave the first portion of the track and then it is set to manual mode where it collects and transport dinosaur toys and Ken dolls, within a designated arena in a specific amount of time. Despite achieving its main objectives, the robot faced challenges such as inadequate weight distribution and intermittent communication failures due to external UDP communication issues, which limited its performance in the final competition. This report discusses the mechanical, electrical, and software configurations of the robot, evaluates its performance limitations, and proposes enhancements such as a gripper-only mechanism and advanced ultrasonic sensors to improve future designs. Through iterative design and testing, this project contributes valuable insights into effective strategies for robotic navigation and object manipulation in competitive environments.

I. INTRODUCTION
The field of robotics has continually advanced through innovations in design and control systems. As a part of the Mechatronics and Robotics Engineering curriculum at Queen’s University, the team was tasked with creating a robotic system capable of navigating autonomously and moving objects manually, specifically toy dinosaurs on the floor and on top of rocks into a bucket and a Ken doll in a trench on the gameboard to a separate location. This report presents the design, development, and operational assessment of our semi-autonomous robot, the DinoDrive Robot.
DinoDrive was designed to line follow a predefined path within the autonomous mode and corral dinosaurs within the mannual mode.
DinoDrive is built upon previous manual and automatic rover designs, while allowing for a seamless transition between autonomous line-following and remote controlled manual mode with a button press. Three servo motors are used to control the scoop and gripper on the arm and two DC motors are used for the robots driving.
The novelty of our work lies in our approach to combining various materials, such as Polylactic Acid (PLA), Thermoplastic Polyurethane (TPU), and Medium-Density Fiberboard (MDF), to construct a versatile and resilient robot tailored for the competition’s unique demands. Moreover, the introduction of an adaptive, soft gripper inspired by Festo’s “Adaptive Gripper Finger DHAS” reflects our dedication to innovation in robotic design.
Our overall strategy was to create a robot that could excel in corralling dinosaurs, hypothesizing that the integration of an adaptive TPU gripper would significantly enhance the robots efficacy. We anticipated that the DinoDrive would not only meet the competition's requirements but also provide insightful data and experience to inform future iterations of robotic design in our field.
Through meticulous planning, iterative design, and extensive testing, the DinoDrive project endeavors to contribute valuable knowledge and methodology to the domains of robotic navigation and object manipulation, particularly in competitive and task-oriented contexts.

II. METHODS
A. Design Dimensions and Materials Used
The mechanical design of the robot consists of mainly a body and arm. To give an idea of its dimensions the robot can be simplified to fit within a 23 cm by 24 cm by 10 cm rectangular prism. The materials used consist of PLA, TPU, and MDF. A more detailed design of the robot can be seen in Fig. 1 and the specific amounts of each material is summarized in Table 1.

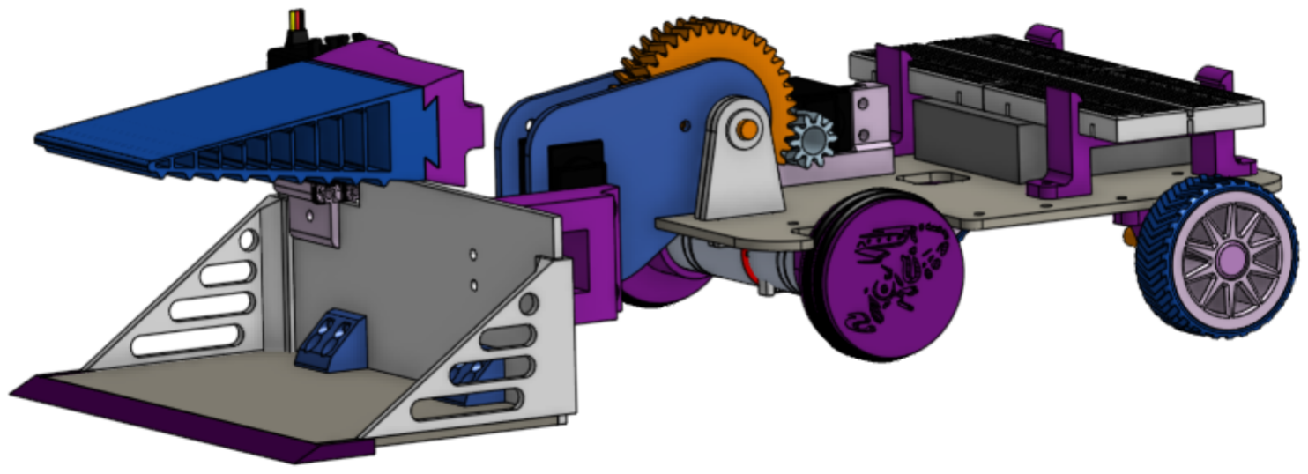
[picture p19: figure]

Fig. 1. DinoDrive Robot CAD made with OnShape.

TABLE I. | MATERIAL USAGE BREAKDOWN FOR ROBOT FABRICATION
Metric | Material
PLA | TPU | MDF
Volume (cm!) | 150 | 90 | N/A
Percentage of total material used | 62.5 | 37.5 | 75

B. Soft Gripper
The primary end effector used in this design was an adaptive gripper, inspired by Festo’s “Adaptive Gripper Finger DHAS.” This gripper is uniquely capable of conforming to objects of various shapes, such as dinosaur models and a Ken doll, due to its morphing capabilities. Enhanced gripping is facilitated by additional indents that increase the surface area in contact with the objects. Constructed from TPU, the gripper was produced using an fused deposition modelling (FDM) 3D printer. The design allows the gripper to wrap more tightly around objects as greater force is applied, effectively adapting to objects with pronounced curvature. This morphing action is illustrated in Fig. 2, as documented by Festo [1].
TPU is a versatile class of polyurethane plastics known for its elasticity, transparency, and resistance to oil, grease, and abrasion. It is a thermoplastic elastomer made from linear segmented block copolymers, which include both hard and soft segments. The hard segments provide toughness and rigidity, enhancing physical performance, while the soft segments impart flexibility and elastomeric traits. This inherent compliance, characteristic of soft robotic systems as noted by Laschi and Cianchetti (2014), allows a soft robotic gripper made of TPU to generate highly passive deformations and adapt to the shape of the object it handles [2]. TPU's benefits extend to robotic applications, particularly in the construction of grippers. Its durability minimizes damage risk while handling objects, making it ideal for repeated use in robotics [3].
NinjaFlex is a prominent brand of TPU known for its exceptional flexibility and strength. It is particularly noted for producing some of the softest TPU available, specifically their formulation that has a shore hardness of 85A. This makes it one of the softest TPUs on the market, providing significant advantages in applications requiring high levels of flexibility and elasticity [4].
The 85A shore hardness rating of NinjaFlex indicates a very soft material, akin to the flexibility of shoe soles or rubber bands. This softness allows for the creation of parts that can withstand bending and flexing forces without cracking or losing form, which is crucial in dynamic environments.

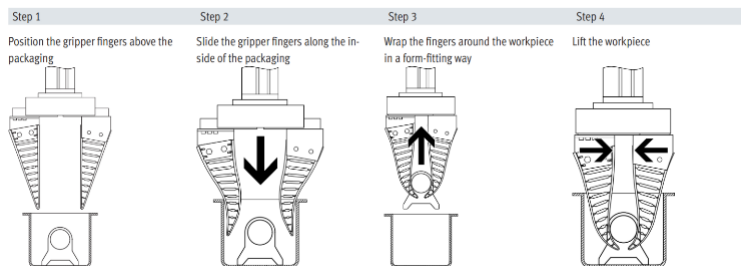
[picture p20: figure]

Fig. 2. Demonstration of Festo gripper adapting to an object.
C. Gear Design
Two double helical gears were incorporated into the design to actuate the arm, which includes both a loader and a gripper. A servo, rated for a torque between 3.3 kg∙cm and 4.1 kg∙cm [5], powered the smaller gear, while the larger gear was directly connected to the arm. The initial design utilized a direct servo connection to the arm; however, due to the excessive weight of the final arm design, this configuration proved inadequate torque, necessitating the addition of gears. The gears, with a ratio of 1:4, consisted of a small gear with 10 teeth and a larger gear with 40 teeth. The double helical gear configuration was selected to enhance load-carrying capacity and tooth durability [6]. The limitation posed by the maximum printable volume of PLA, which required the use of a low infill percentage, was mitigated by the helical design, ensuring durability of the teeth independent of the infill percentage. Fig. 3 depicts the gear assembly. This gearing arrangement proved effective for lifting both the arm and the simulated loads, represented by either a dinosaur model or a Ken doll.

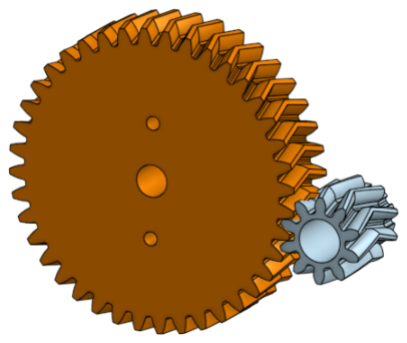
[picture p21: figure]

Fig. 3. Gear train with a 1:4 gear rario for lifitng the arm (scooper and gripper).
D. Wheel Design
The front and rear wheels of the robot are illustrated in Fig.4 and Fig. 5, respectively. The front wheels are designed with two indents to securely accommodate the Buna N cord, which was cut diagonally and adhered using super glue. To enhance the traction on the arena surface, each front wheel was equipped with two rubber wires. Additionally, the rear side of each front wheel includes a space designed for a press-fit connection with the DC motor shaft. Conversely, the rear wheels are mounted on freely spinning axles. The wheels utilize blue TPU for improved traction and purple PLA for the inner wheel structure. The pattern on the wheels, while not chosen for any specific technical advantage, was designed to increase the surface area for better traction.
Fig. 4. Front | wheels | of the
DinoDrive robot.

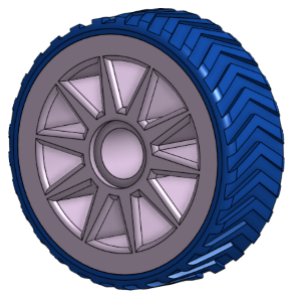
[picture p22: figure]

Fig. 5. Back/rear wheels of the DinoDrive Robot.

E. Software and Control Algorithms
The team implemented software and control algorithms to navigate a rover with the ability to drive manually using a Logitech F310 Wired Gamepad and automatically using the DFRobotShop Rover Line Follower. Additionally, the team implemented an arm control mechanism for both picking up the dinosaur toys and Ken doll. The software is written in both Python and Arduino script for communicating with the Gamepad to control the robot’s microcontroller operations.

a) Manual Drive Control: User Datagram Protocol (UDP) communication between the controller and the rover was enabled by utilizing the inputs library within the python script to interface with the gamepad. The rover’s movements coud be mannualy controlled wirelessly with over the air (OTA) updates enabling real-time transmission of control signals. The rover was able to execute both directional movement and speed adjustment using front wheel drive.
b) Automatic Line Following Control: Upon activation with a button press, the Arduino script running on the rover's microcontroller alowed the rover to navigate a predetermined path marked by a black line on the track. The rover could detect the line and adjust its course as needed with the help of a control loop. Proportional-integral (PI) control algorithms were used to process sensor inputs and calculate the necessary steering adjustments to to refine the rover’s path following accuracy.
c) Arm Control: The arm of the rover was controlled by three servo motors. The first two servos were programmed to control the location of the arm and the final servo was used to open and close the gripper. The arduino script included bounds such that the servos can only rotate within a safe range to avoid any mechanical interferances with other parts of the rover’s structure. The Python script controlled the arm via gamepad inputs and was changed to include a condition that not only checked for when a button was pressed, but also when a button is released after being pressed. This way the arms movements were both smooth and responsive to the operator's input.
F. Electrical Design
The main components of the electrical design of the rover can be seen as the physical electrical subsystem in Fig. 6 and an electrical schematic in Fig. 7.

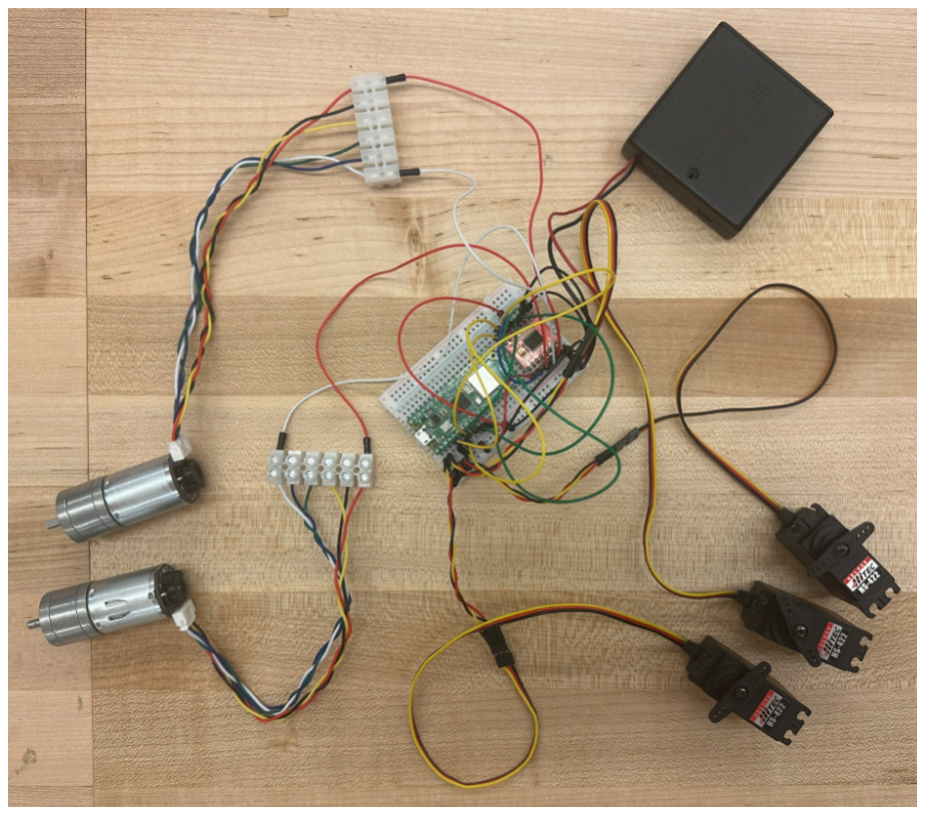
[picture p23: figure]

Fig. 6. The physical electrical subsystem for DinoDrive robot.

Fig. 7. Electrical schematic for DinoDrive robot made using Cirkit Designer.
Given a full charge the battery pack will allow the rover to run for approximately 44 minutes to 2 hours and 56 minutes. However the torque the servo motors can handle and the speed the DC motors will run at decline with a lower charge. The power budget for the main rover components are portrayed in Table 2.
TABLE II. | POWER BUDGET FOR DINODRIVE ROBOT
Component | Nominal Voltage (V) | Nominal Current Draw (A) | “worst-case” Current Draw (A) | Nominal Power (W) | “worst-case” Power (W)
Servo Motor x 3 | 4.8-6.0 | 0.15 | 0.15 | 0.72 | 0.9
DC Motor x 2 | 6 | 0.13 | 3.2 | 0.78 | 19.2
Motor Driver | 5.5 | 1.2 | 1.2 | 6.6 | 6.6
Raspberry Pi Pico W | 1.8-5.5 | 0.5 | 0.9 | 2.75 | 4.95
Total | 33.7-330 | 2.41 | 8.55 | 11.22 | 52.65

III. RESULTS
A. Autonomous Mode
During the testing, the robot was able to line follow and get through the door using integral control more than half of the time. The robot had no issues when moving in a straight line, the problems began when the robot attempted to turn using line following which was reflected during the qualifying rounds when the robot missed the left turn. To mitigate this error proportional control was added in order to adjusts the robot's steering based on the current error. While this change increased the rate at which the robot can complete the turn to about 80% of the time, the robot missed the turn once again during the final competition.
B. Manual Mode
The robot's manual mode proved to be effective, successfully picking up dinosaurs of various shapes. The control system consisted of three servos: one for tilting the gripper/loader, another for operating the gripper, and a third for raising the arm. Each servo was linked to two buttons—one to rotate the servo clockwise and the other counterclockwise. The buttons were designed to be press-and-hold for operation, with the right button of each pair configured to raise the arm and the left to lower it. Specifically, Servo 1 (Tilting scoop) was controlled by the RB and LB buttons, Servo 2 (Gripper) by the A and B buttons, and the arm lifting by the X and Y buttons. The robot's driving was managed through thumb sticks: the left stick controlled forward and backward movement, while the right stick handled turning, gradually adjusting the speed to each wheel based on the direction of the turn. This layout made driving and operating the arm both easy and intuitive. The robot responded promptly to these controls, exhibiting no noticeable delay. Initial testing rounds were essential for becoming familiar with the robot's movements and optimizing the button mappings. After three iterations of refinement, the final design of the control layout was established, enhancing the overall usability of the robot.

IV. DISCUSSION
A. Robot Performance
The robot's performance was close to expectations, with its primary objective being to collect four dinosaur toys and disregarding the Ken doll. The line-following functionality was operational approximately 80% of the time, with performance inconsistencies largely attributed to variations in battery power. This fluctuation hindered the ability to make precise adjustments in the code. In autonomous mode, line-following issues were particularly noticeable after the arena's designated turn point. In manual mode, the robot managed to collect only one dinosaur due to time constraints and a code timeout caused by UDP communication errors that were beyond the teams control. However, the scooper and loader were successful in gripping and transporting the dinosaurs to the designated dropoff cage.
B. Limitations and Proposed Improvments
Several limitations were observed in the robot's design and functionality:
a) Weight Distribution: The robot's weight was distributed in such a manner that picking up Ken dolls was impractical. Redesigning the weight balance could enhance versatility in object handling.
b) Line Following Code: The line-following code had a success rate of only 80%. Improving the algorithm and incorporating adaptive features to better handle power variability could increase reliability.
c) Scooper and Arm Mechanism: Occasionally, the scooper and arm pushed the dinosaurs away instead of scooping them up. A design shift towards a gripper-only mechanism might yield better results in securing and lifting objects.
d) Sensor Enhancement: Integrating high-quality ultrasonic sensors would improve the robot's environmental awareness, potentially enhancing navigation and object detection capabilities.
These improvements are aimed at overcoming the current limitations, thereby enhancing the robot's operational efficiency and reliability in future iterations.
C. Conclusion
The study detailed in this report outlines the design and operational testing of the DinoDrive, a semi-autonomous robot. This robot is engineered to navigate a specified path and manipulate objects within a competitive setting, primarily focusing on collecting dinosaur toys while avoiding static obstacles like rocks and walls. The DinoDrive operates under a dual-mode system, alternating between autonomous line-following and manual control via controller input change, enhancing usability and precision in object handling. Although the robot achieved its fundamental goals, it encountered issues related to weight distribution and communication errors, impacting its performance in critical situations. The proposed future enhancements, including a shift to a gripper-only mechanism and the addition of ultrasonic sensors, aim to refine its capabilities. This project illustrates the potential for iterative design processes to advance robotic technology in complex, task-oriented environments.

CREDIT AUTHORSHIP CONTRIBUTION STATEMENT
Aria Maz: Conceptualization, Data Curation, Formal analysis, Investigation, Software, Visualization, Writing -Original Draft. Daniel Dubinko: Conceptualization, Data Curation, Formal analysis, Investigation, Methodology, Software, Visualization, Writing - Review & Editing. Amy Wu: Resources, Supervision. Graziella Bedenik de Oliveira: Supervision. Jenny Lee: Supervision. Abigail Lee: Supervision
V. REFERENCES
[1]
\

FESTO, "Adaptive gripper fingers DHAS," FESTO, [Online]. Available:
https://www.festo.com/media/pim/049/D15000100122049.PDF . [Accessed 17 April 2024].
[2] A. K. e. al, "3D-Printed Pneumatically Controlled Soft Suction Cups for Gripping Fragile, Small, and Rough Objects," Wiley Online Library, 01 July 2021. [Online]. Available: https://onlinelibrary.wiley.com/doi/full/10.1002/aisy.20210003
4. [Accessed 17 April 2024].
[3] s. bajaj, "What is TPU Material | The Definitive Guide," 4
October 2023. [Online]. Available: https://plasticranger.com/what-is-tpu-material/. [Accessed 17 April 2024].
[4] NinjaTek, "NINJAFLEX 3D PRINTER FILAMENT (85A)," NinjaTek, [Online]. Available: https://ninjatek.com/shop/ninjaflex/. [Accessed 17 April 2024].
[5] "HS-422 Deluxe Standard Servo," HiTEC, [Online]. Available: https://hitecrcd.com/products/servos/analog/sport-2/hs-422/product. [Accessed 17 April 2024].
[6] "Helical Gears vs. Spur Gears," Gear Motions, 15 February 2017. [Online]. Available: https://gearmotions.com/helicalgears-vs-spur-gears/. [Accessed 17 April 2024].

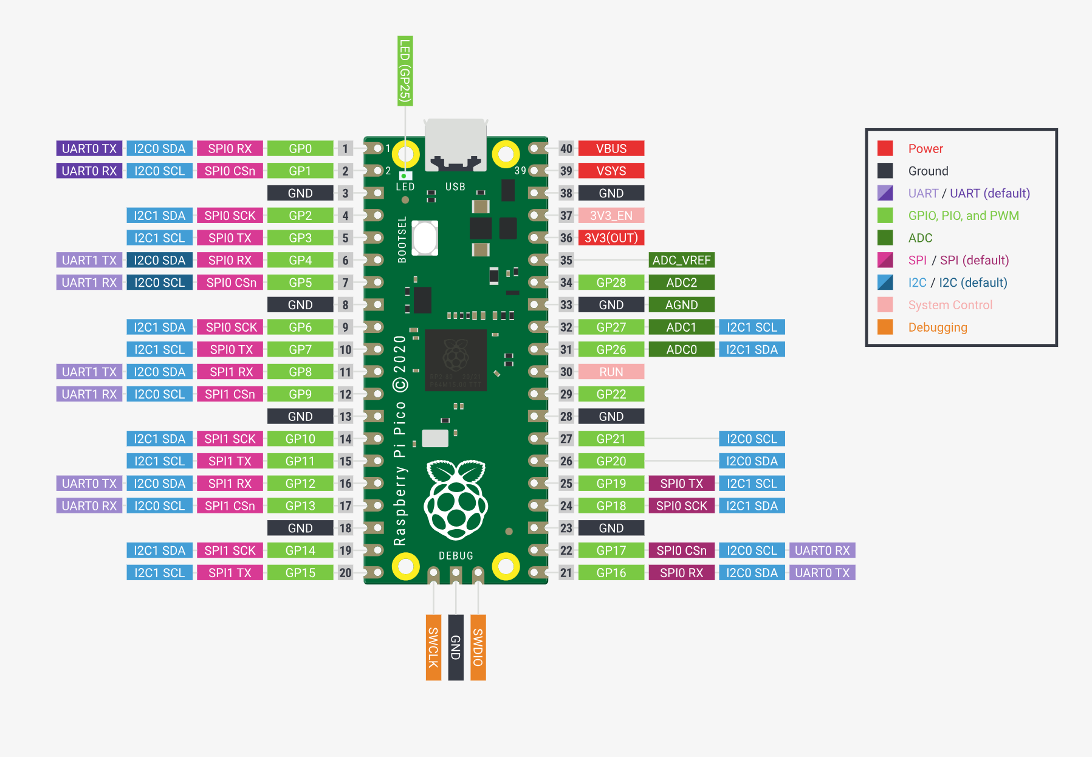
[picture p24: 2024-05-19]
Images/RaspPiDataSheet.png

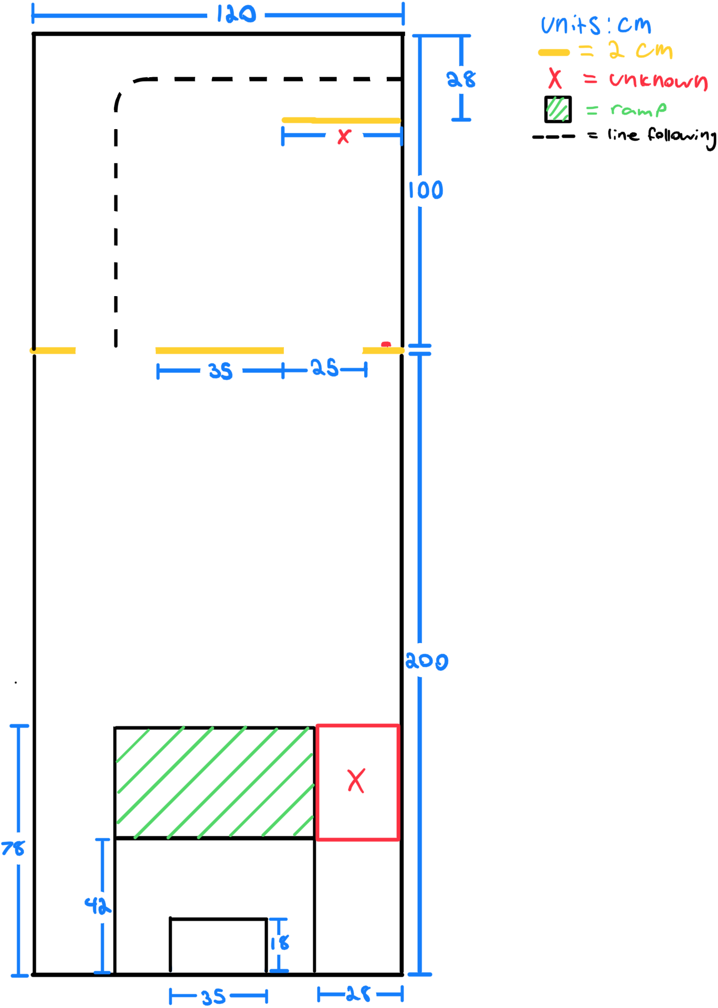
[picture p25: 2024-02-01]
Images/MREN303Arena.png

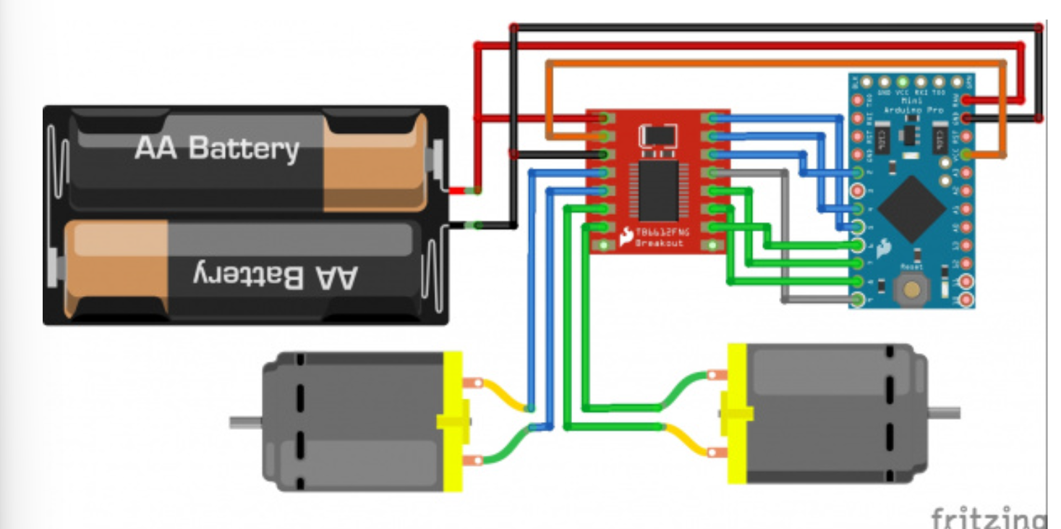
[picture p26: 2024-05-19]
Images/MotorDriverPinOut.png

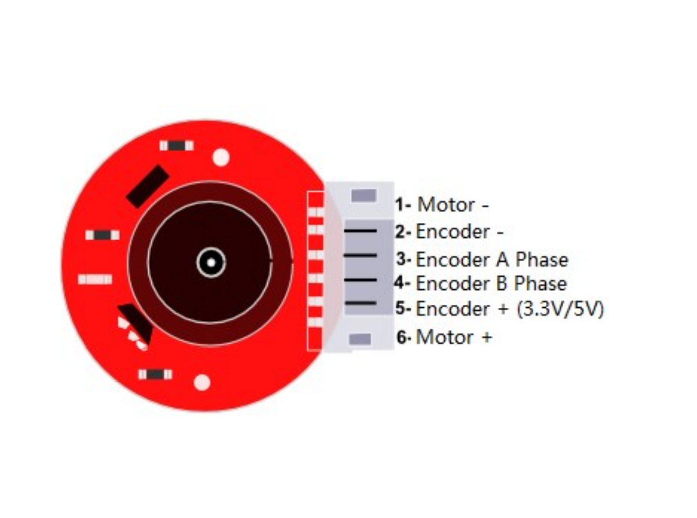
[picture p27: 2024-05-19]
Images/DC_Motor_PinOut.png

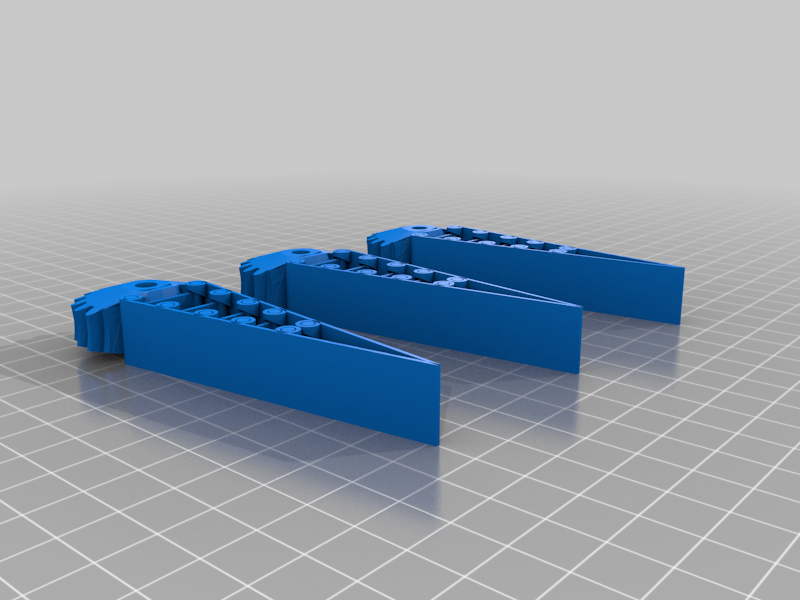
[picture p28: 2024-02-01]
Images/Gripper.png

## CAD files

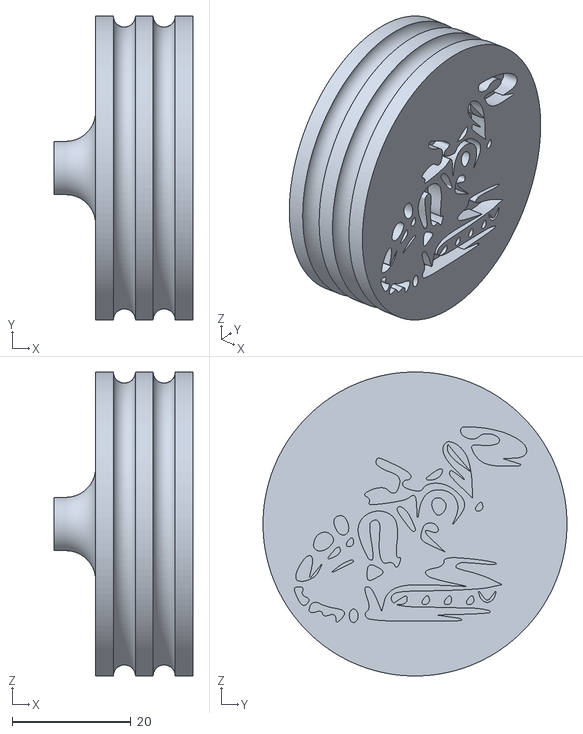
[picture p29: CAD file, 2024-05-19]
STL_Files/PLA/Casing + Wheels - 3D Printed Back Wheels.stl
23.4 x 51.2 x 51.2

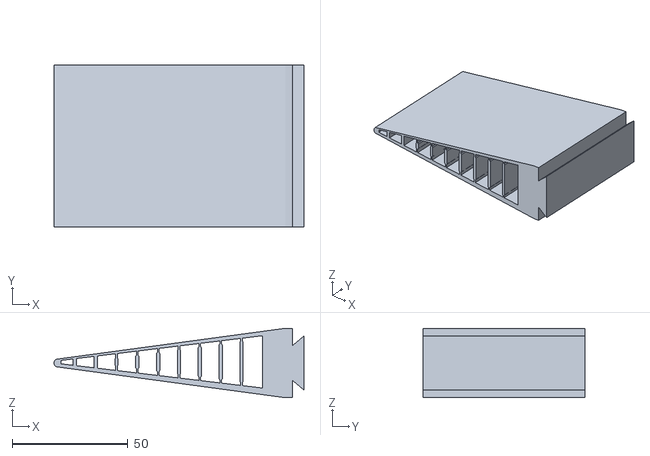
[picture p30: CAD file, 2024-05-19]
STL_Files/TPU/Adaptive Gripper v2 TPU.stl
108.0 x 70.0 x 30.0

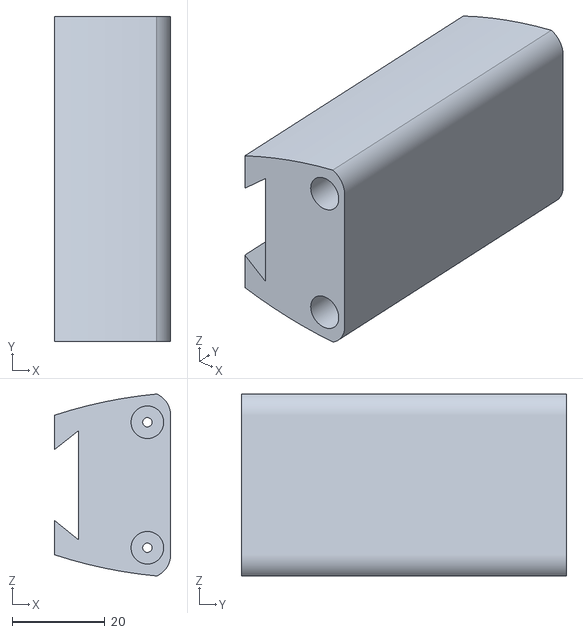
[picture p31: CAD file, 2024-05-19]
STL_Files/PLA/Servo Wings - Gripper Servo Attachment.stl
25.0 x 70.0 x 39.1

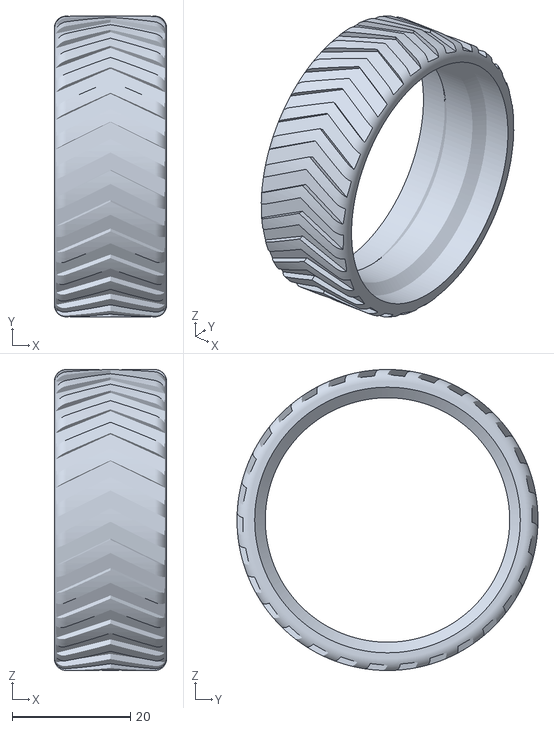
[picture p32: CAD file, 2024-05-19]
STL_Files/TPU/Front Wheel Tire TPU.stl
19.0 x 51.0 x 51.0

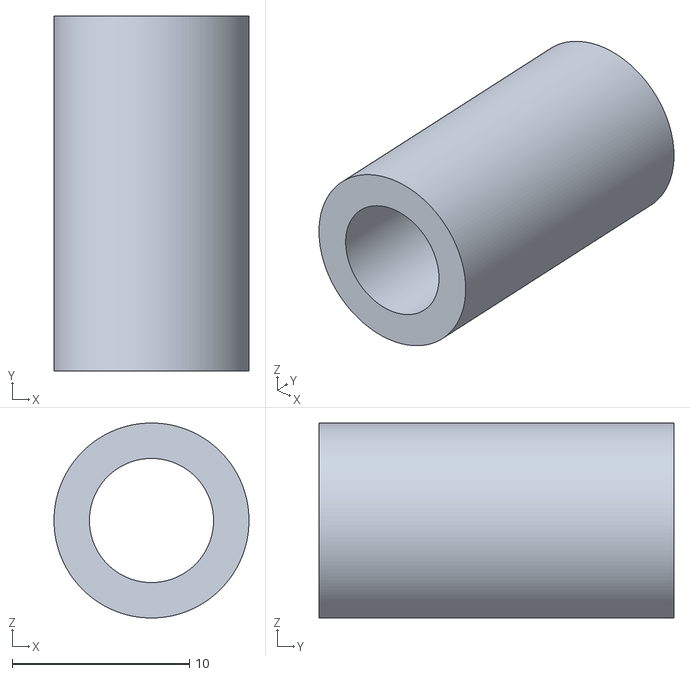
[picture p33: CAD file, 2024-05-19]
STL_Files/PLA/Casing + Wheels - Front Wheel Spacers.stl
11.0 x 20.0 x 11.0

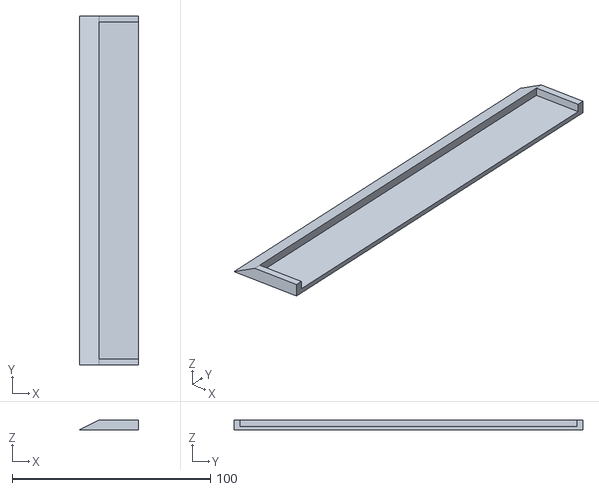
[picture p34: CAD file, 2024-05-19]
STL_Files/PLA/Crane - Angled Scoop Head.stl
30.0 x 176.0 x 5.00

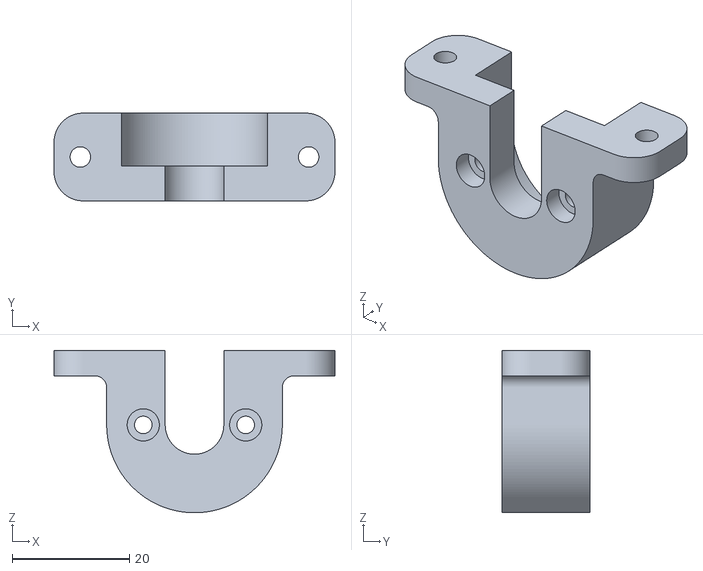
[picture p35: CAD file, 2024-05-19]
STL_Files/PLA/DC Motor - Motor Strap Front.stl
48.0 x 15.0 x 27.8

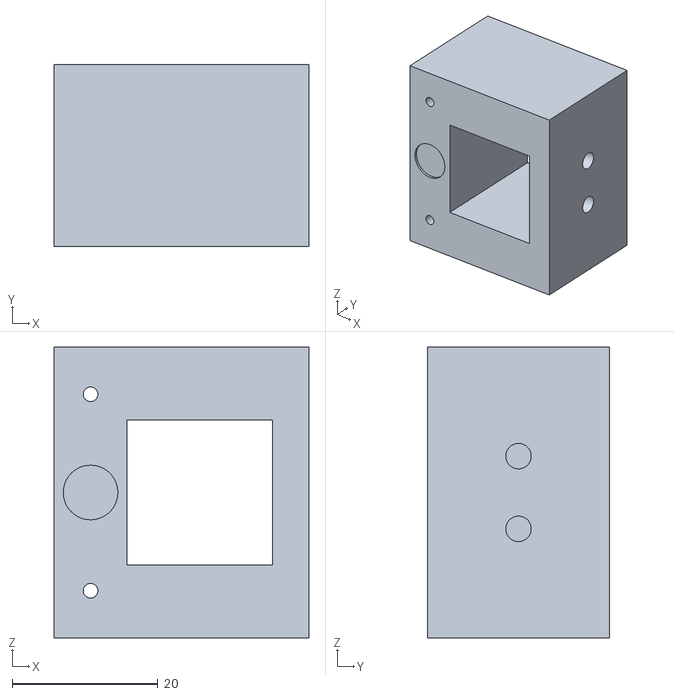
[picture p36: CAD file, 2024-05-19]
STL_Files/PLA/Servo Wings - Scoop Servo Attachment.stl
35.0 x 25.0 x 40.0

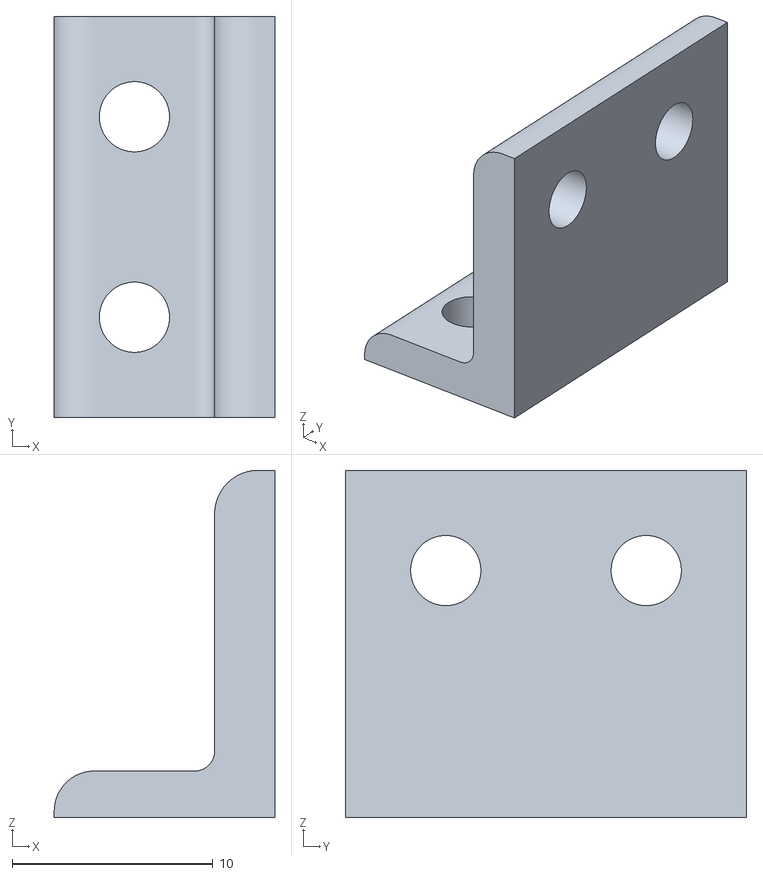
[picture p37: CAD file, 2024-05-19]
STL_Files/PLA/Crane - Scoop Holder.stl
11.0 x 20.0 x 17.3

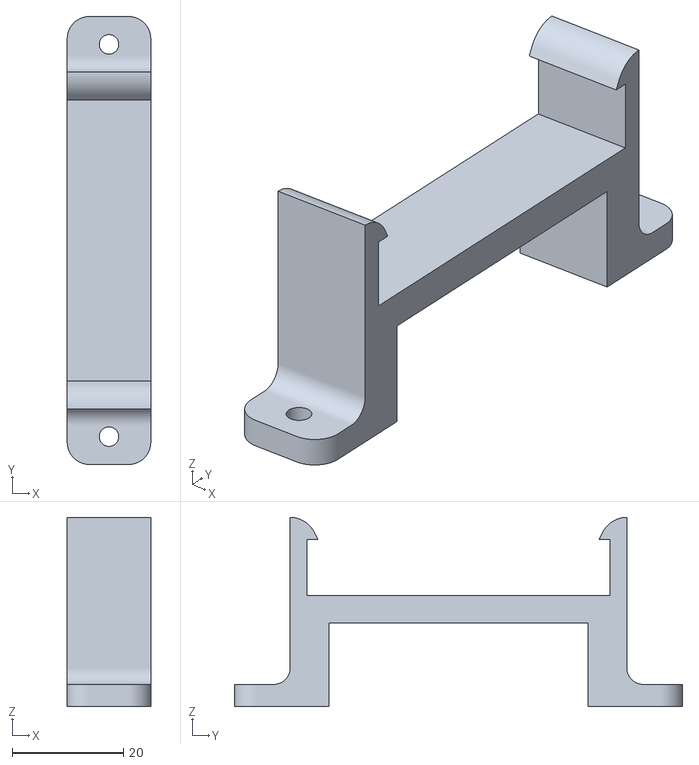
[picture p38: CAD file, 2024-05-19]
STL_Files/PLA/Casing + Wheels - Breadboard Clip.stl
15.0 x 80.4 x 34.0

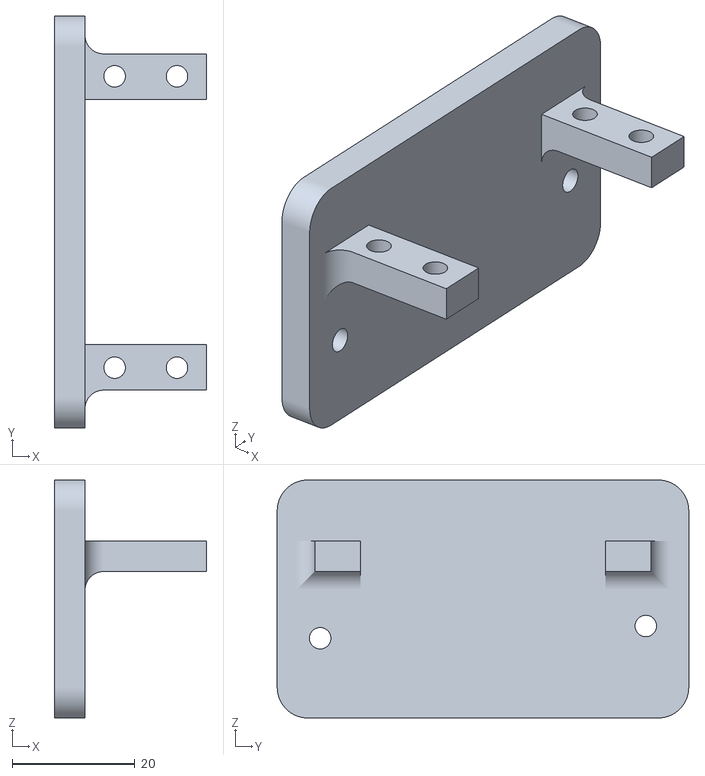
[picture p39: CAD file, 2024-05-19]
STL_Files/PLA/Servo Motor - Casing Servo Mount.stl
24.8 x 67.1 x 38.8

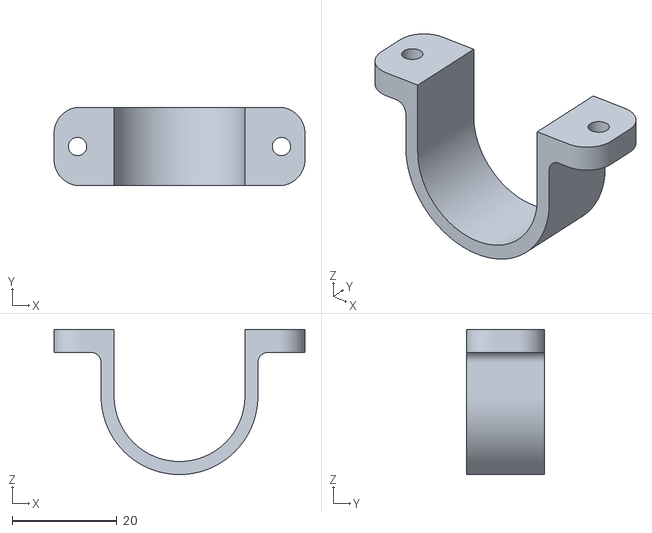
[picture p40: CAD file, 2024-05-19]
STL_Files/PLA/DC Motor - Motor Strap Back.stl
48.0 x 15.0 x 27.8

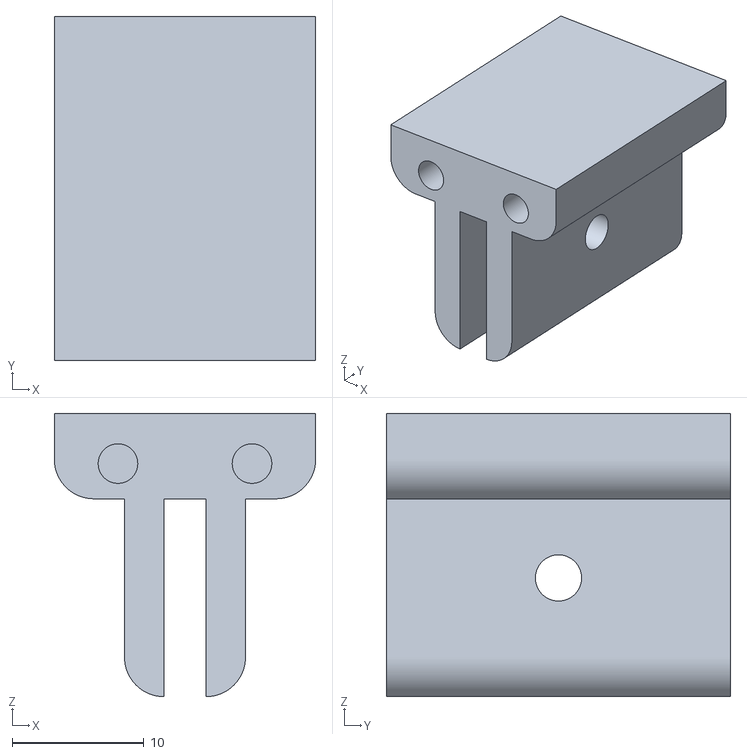
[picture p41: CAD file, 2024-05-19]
STL_Files/PLA/Crane - Scoop Servo Holder.stl
19.8 x 26.1 x 21.5

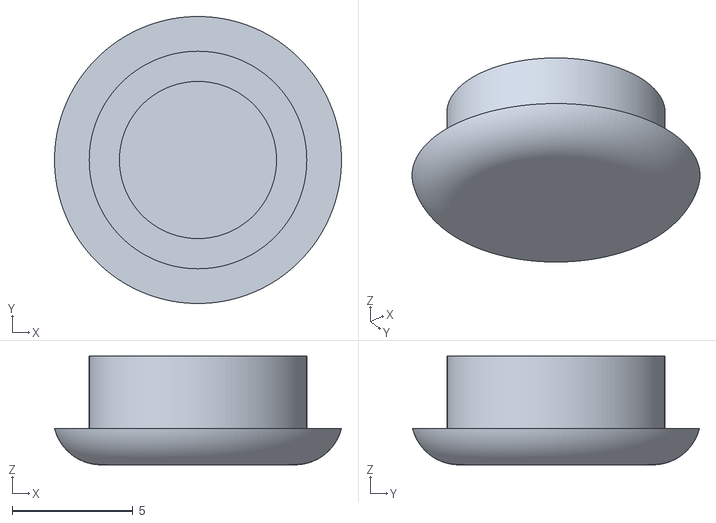
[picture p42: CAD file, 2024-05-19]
STL_Files/PLA/Casing + Wheels - Axel Caps.stl
11.9 x 11.9 x 4.50

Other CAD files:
STL_Files/PLA/Casing + Wheels - Front Wheel Support.stl
STL_Files/PLA/Front Wheel Center PLA.stl

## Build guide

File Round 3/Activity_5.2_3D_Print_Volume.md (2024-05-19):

# 3D Print Volume Tracking 
## Total Volume: 245806 mm^3
*refer to [STL Files Folder][1]

[1]: https://code.engineering.queensu.ca/mren303_w2024/section003_group10_dinodrive/-/tree/main/STL_Files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

| Part Name | Status |
| --- | --- |
| Back Wheels Axle Left | Printing |
| Back Wheels Axle Right | Awaiting Printing |
| DC Motor Casing Attachment Left  | Printing |
| DC Motor Casing Attachment Right  | Awaiting Printing |

| Part Name | Volume | Total Volume Left  |
| --- | --- | --- |
| Back Wheels Axle Left | 1174 |244632 |
| DC Motor Casing Attachment Left  | 8740 | 235892 |

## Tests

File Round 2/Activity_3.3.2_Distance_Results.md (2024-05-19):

The ultrasonic sensor performs well within the teams tested distances of 5-100 cm relative to its stated sensing range of 2 cm to 400 cm. This is quantified by the value of R<sup>2</sup> in Table 1 (the linear regression model fits the data almost perfectly) and portrayed visualy when comparing the distance line to the line of unity in Figure 1.

**Table 1:** Table of distance measurements.
| # | Actual Distance (cm) | Measured Distance (cm) | Slope | R<sup>2</sup> |
|---|---|---|---|---|
| 1 | 5 | 5 |0.9934 |0.9997 |
| 2 | 10 | 11 | | |
| 3 | 25 | 25 | | |
| 4 | 50 | 49 | | |
| 5 | 100 | 100 | | |

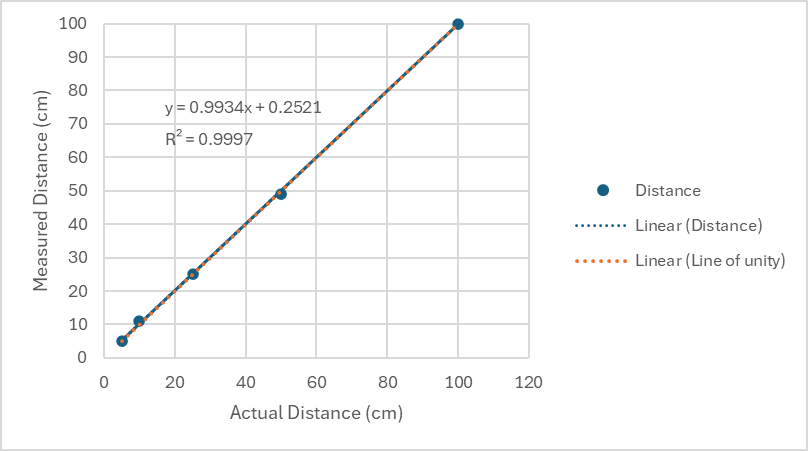
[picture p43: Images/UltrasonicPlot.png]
<br>
**Figure 1:** Plot of distance measurements.

**Reference:**
Fernando, J. (no date) R-squared: Definition, calculation formula, uses, and limitations, Investopedia. Available at: https://www.investopedia.com/terms/r/r-squared.asp#:~:text=To%20calculate%20the%20total%20variance,you%20have%20the%20R%2Dsquared. (Accessed: 07 February 2024).

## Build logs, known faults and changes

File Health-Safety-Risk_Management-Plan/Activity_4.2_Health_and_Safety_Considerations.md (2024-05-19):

# Health and Safety Plan

## General Safety
### Emergency Communication: 
- Consideration: establish a communication plan for emergencies in team meetings
- Mitgation: ensure all team members have an emergency contact, establish a communcation method (e.g. group messaging), and be able to identify two evacuation doors in the lab, as well as evactuation doors in the building. 

### First Aid Kit: 
- Consideration: Have a well-equipped first aid kit readily available.
- Mitigation: Regularly check and restock the first aid kit. Ensure team members know the kit's location and how to use basic first aid supplies.

## Component and Prototype Fabrication: 
### Material Handling 
- Consideration: Provide guidline for the safe handling of materials (e.g., sharp objects, hot surfaces).
- Mitigation: Ensure team members wear appropriate personal protective equipment (PPE), such as gloves or safety glasses, when handling materials. Provide training on safe material handling practices.

### Machine Safety
- Consideration: Identify potential hazards associated with the use of machinery (e.g., CNC machines, power tools).
- Mitigation: Conduct thorough training sessions on the proper use of machinery. Implement safety interlocks and guards on machines. Ensure all team members wear appropriate PPE when operating machinery. Complete tests regarding the equipment to display proof of competency. 

## Battery Safety Measures:
### Storage of Batteries:
- Consideration: Safely store batteries when not in use.
- Mitigation: Use designated storage containers for batteries, away from heat sources. Regularly inspect and replace damaged storage containers.

### Battery Disposal:
- Consideration: Provide guidelines for proper battery disposal.
- Mitigation: Clearly communicate the proper disposal procedures for batteries, ensuring compliance with local regulations. Establish a designated collection point for used batteries.

## Workshop Safety:
### Fire Safety:
- Consideration: Implement fire safety measures in the workshop.
- Mitigation: Install fire extinguishers. If fire extignuishers are already available, ensure that all team members know their locations and how to use them. Conduct regular fire drills.

### Tool Inspection:
- Consideration: Regularly inspect and maintain workshop tools.
- Mitigation: Establish a schedule for tool inspections and maintenance. Immediately address and repair any faulty tools. Provide training on safe tool usage. Only use tools in specified locations.

## Round 2 Review:
The team has reviewed the plan at the beginning of Round 2 and has decided the health and safety plan is thorough and therefore no new mitigation plans are required to be added or revised.

The team is meeting the plan in areas that apply to stages of the project that are bring worked on such as general safety and plans to meet aspects of the plan that will be worked on when the team reaches the apropriate stage such as machine and workshop safety.

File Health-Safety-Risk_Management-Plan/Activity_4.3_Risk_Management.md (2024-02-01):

# Risk Managment 

## Potential Risks 
1. Design and Iteration Errors
2. Team Coordination
3. Software and Hardware Integration
4. Damaging or Damaged Parts
5. Safety While Handling Parts and Tools
6. Component Reliability
7. Team Communication

## Risk Assessment Matrix

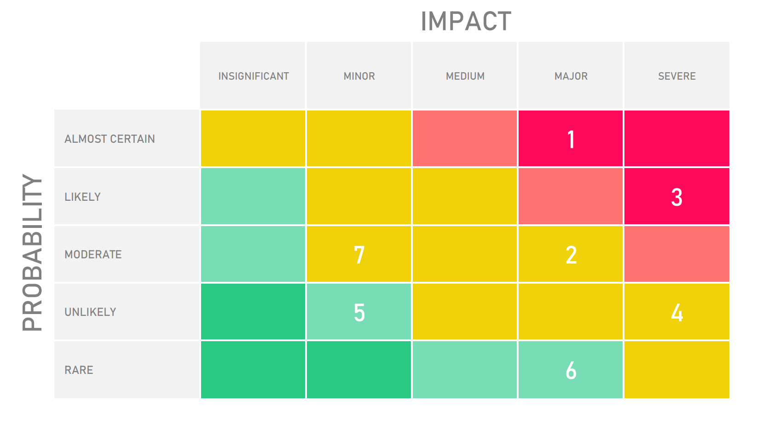
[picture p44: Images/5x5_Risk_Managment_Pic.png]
Risk Managment Rating


## Response Plan

1. **Design and Iteration Errors**
   - Mitigation: Implement a thorough design review process. Conduct iterative testing and validation before finalizing designs.

## Response Plan

1. **Design and Iteration Errors**
   - *Mitigation:* Implement a thorough design review process. Conduct iterative testing and validation before finalizing designs. Example: Ensure 3D printed parts are measurmented correctly and tolerances are added. Monitor the start of the print to mitigate error.

2. **Team Coordination**
   - *Mitigation:*   Utilize collaboration tools such as Notion, Calender, or Reminders, etc, to facilitate communication. Maintain open communication channels and hold regular team meetings. 

3. **Software and Hardware Integration**
   - *Mitigation:* Plan and execute comprehensive integration testing. Ensure compatibility between software and hardware components. Try to integrate hardware and software early on to eliminate large error in the future. Have smaller fails sooner rather than larger fails later. 

4. **Damaging or Damaged Parts**
   - *Mitigation:* Implement proper handling procedures for components. Conduct regular inspections for any signs of damage. Read data sheets prior to testing components. 

5. **Safety While Handling Parts and Tools**
   - *Mitigation:* Enforce the use of personal protective equipment (PPE). Provide training on safe handling practices for both parts and tools.

6. **Component Reliability**
   - *Mitigation:* Conduct thorough reliability testing for components. Establish redundancy or backup plans for critical components. Do prior calculations such as torque load, etc, to understand componenet limits.

7. **Team Communication**
   - *Mitigation:* Establish clear communication channels. Hold regular team meetings and encourage open communication. Speak freely to teammates in a professional or friendly way to avoid any confrontation when discussing a problem. Warn teammates early of any sicknesses or time conflicts.

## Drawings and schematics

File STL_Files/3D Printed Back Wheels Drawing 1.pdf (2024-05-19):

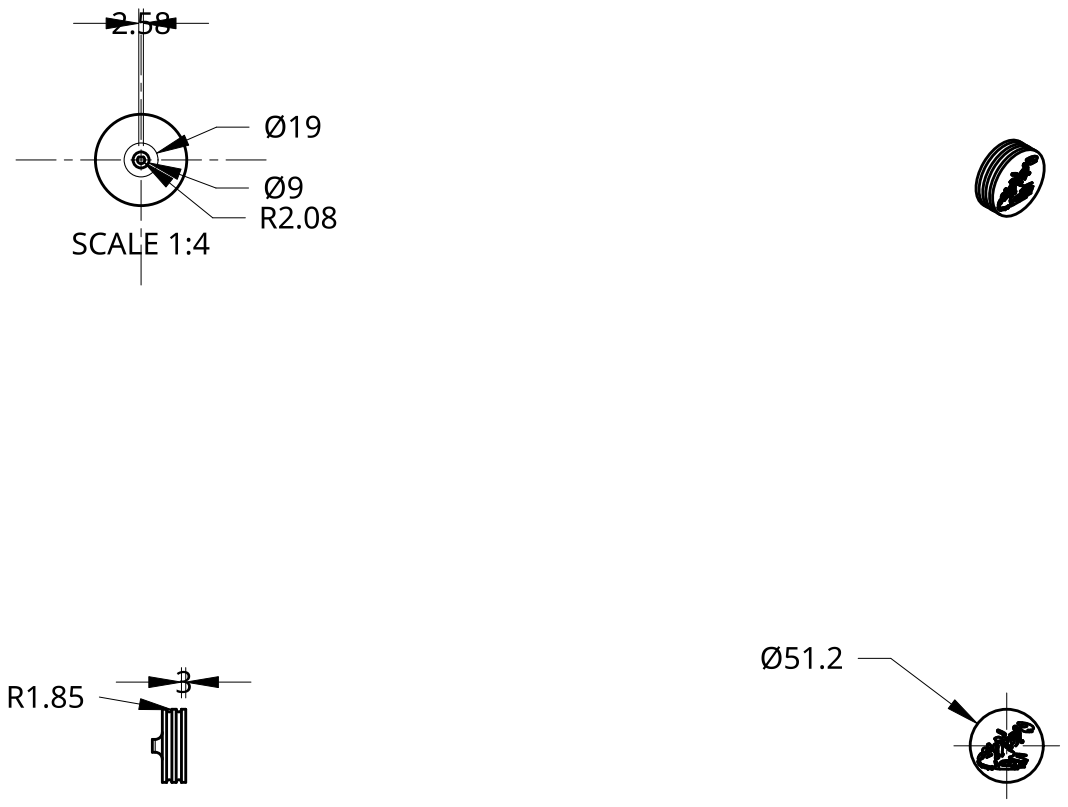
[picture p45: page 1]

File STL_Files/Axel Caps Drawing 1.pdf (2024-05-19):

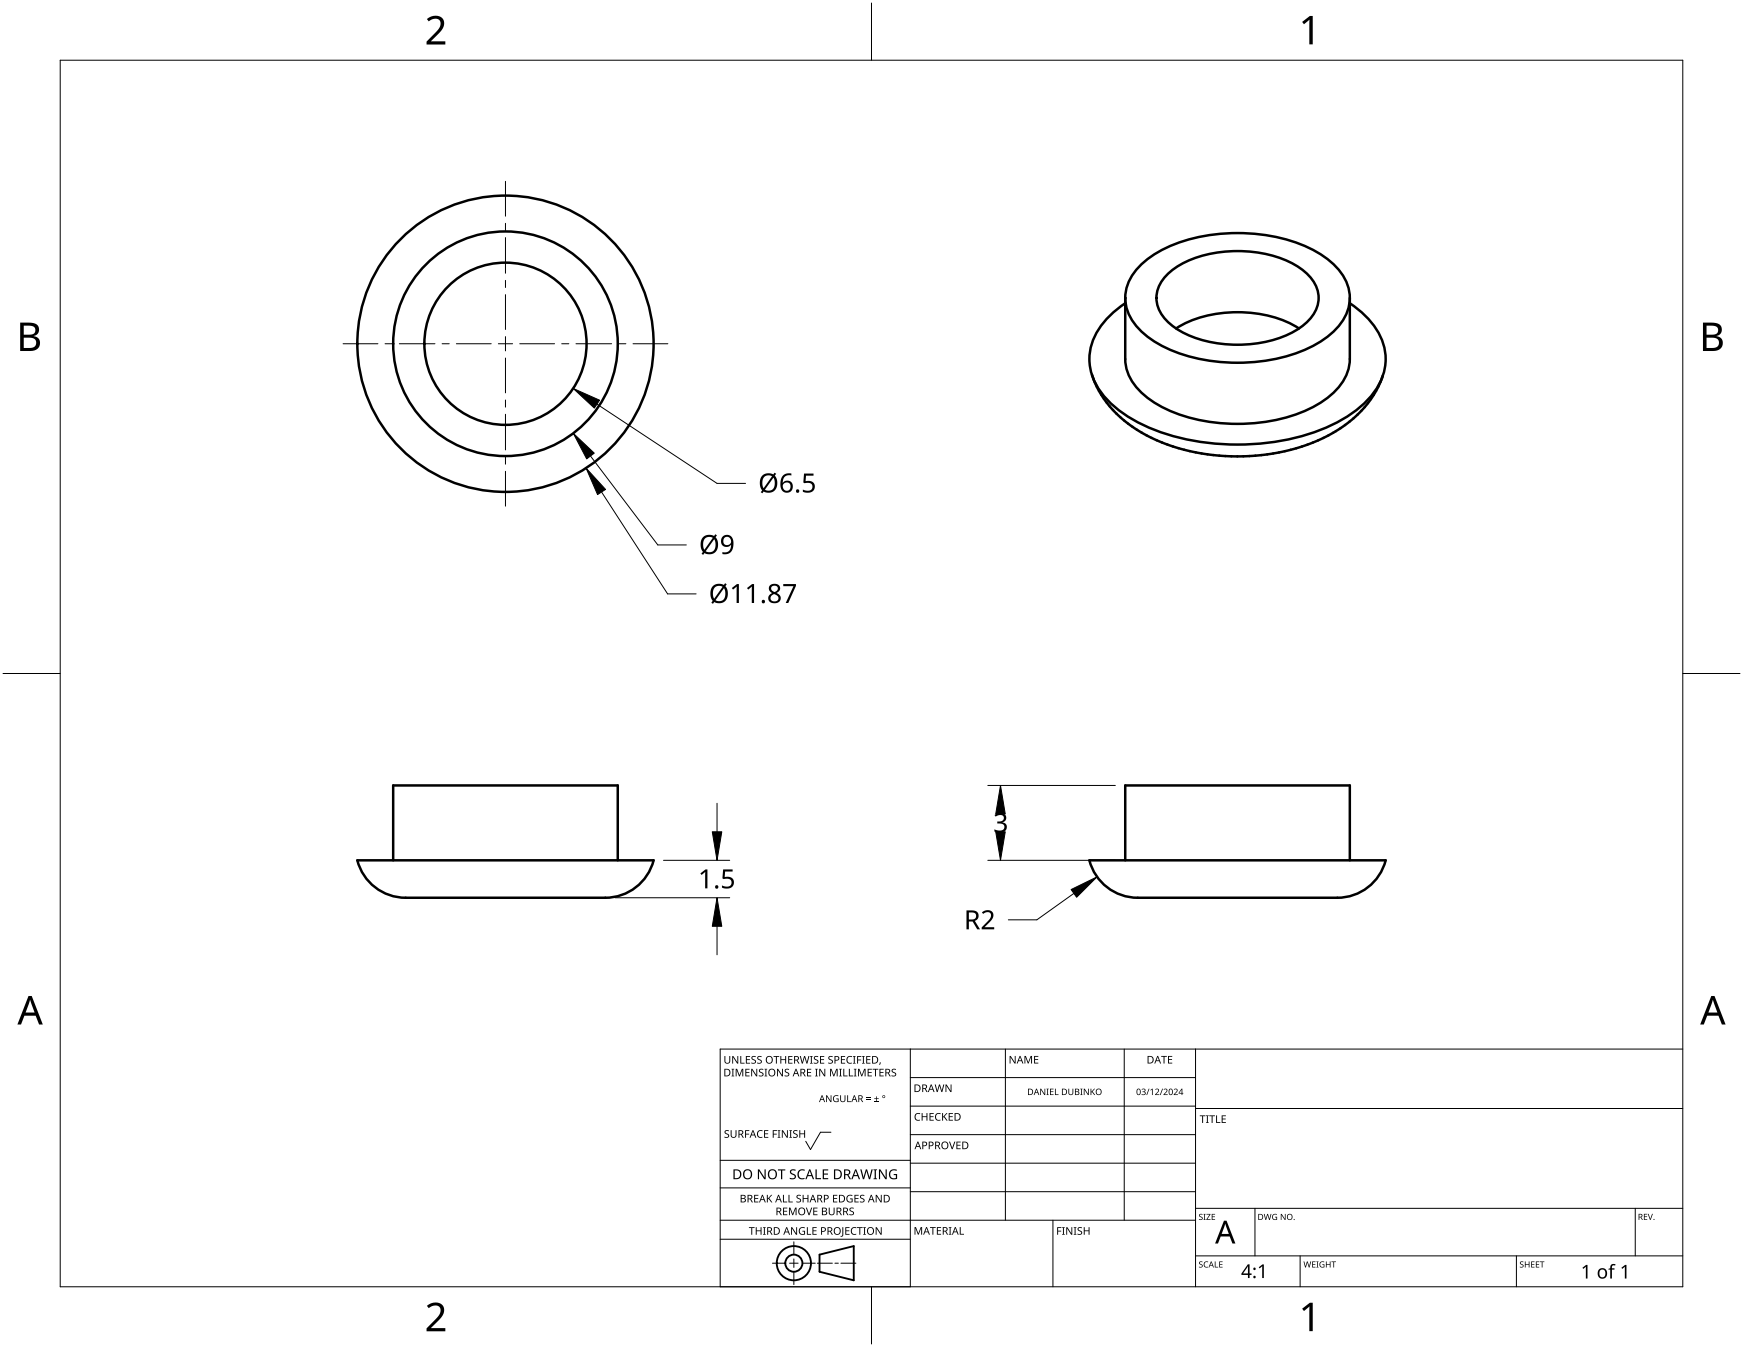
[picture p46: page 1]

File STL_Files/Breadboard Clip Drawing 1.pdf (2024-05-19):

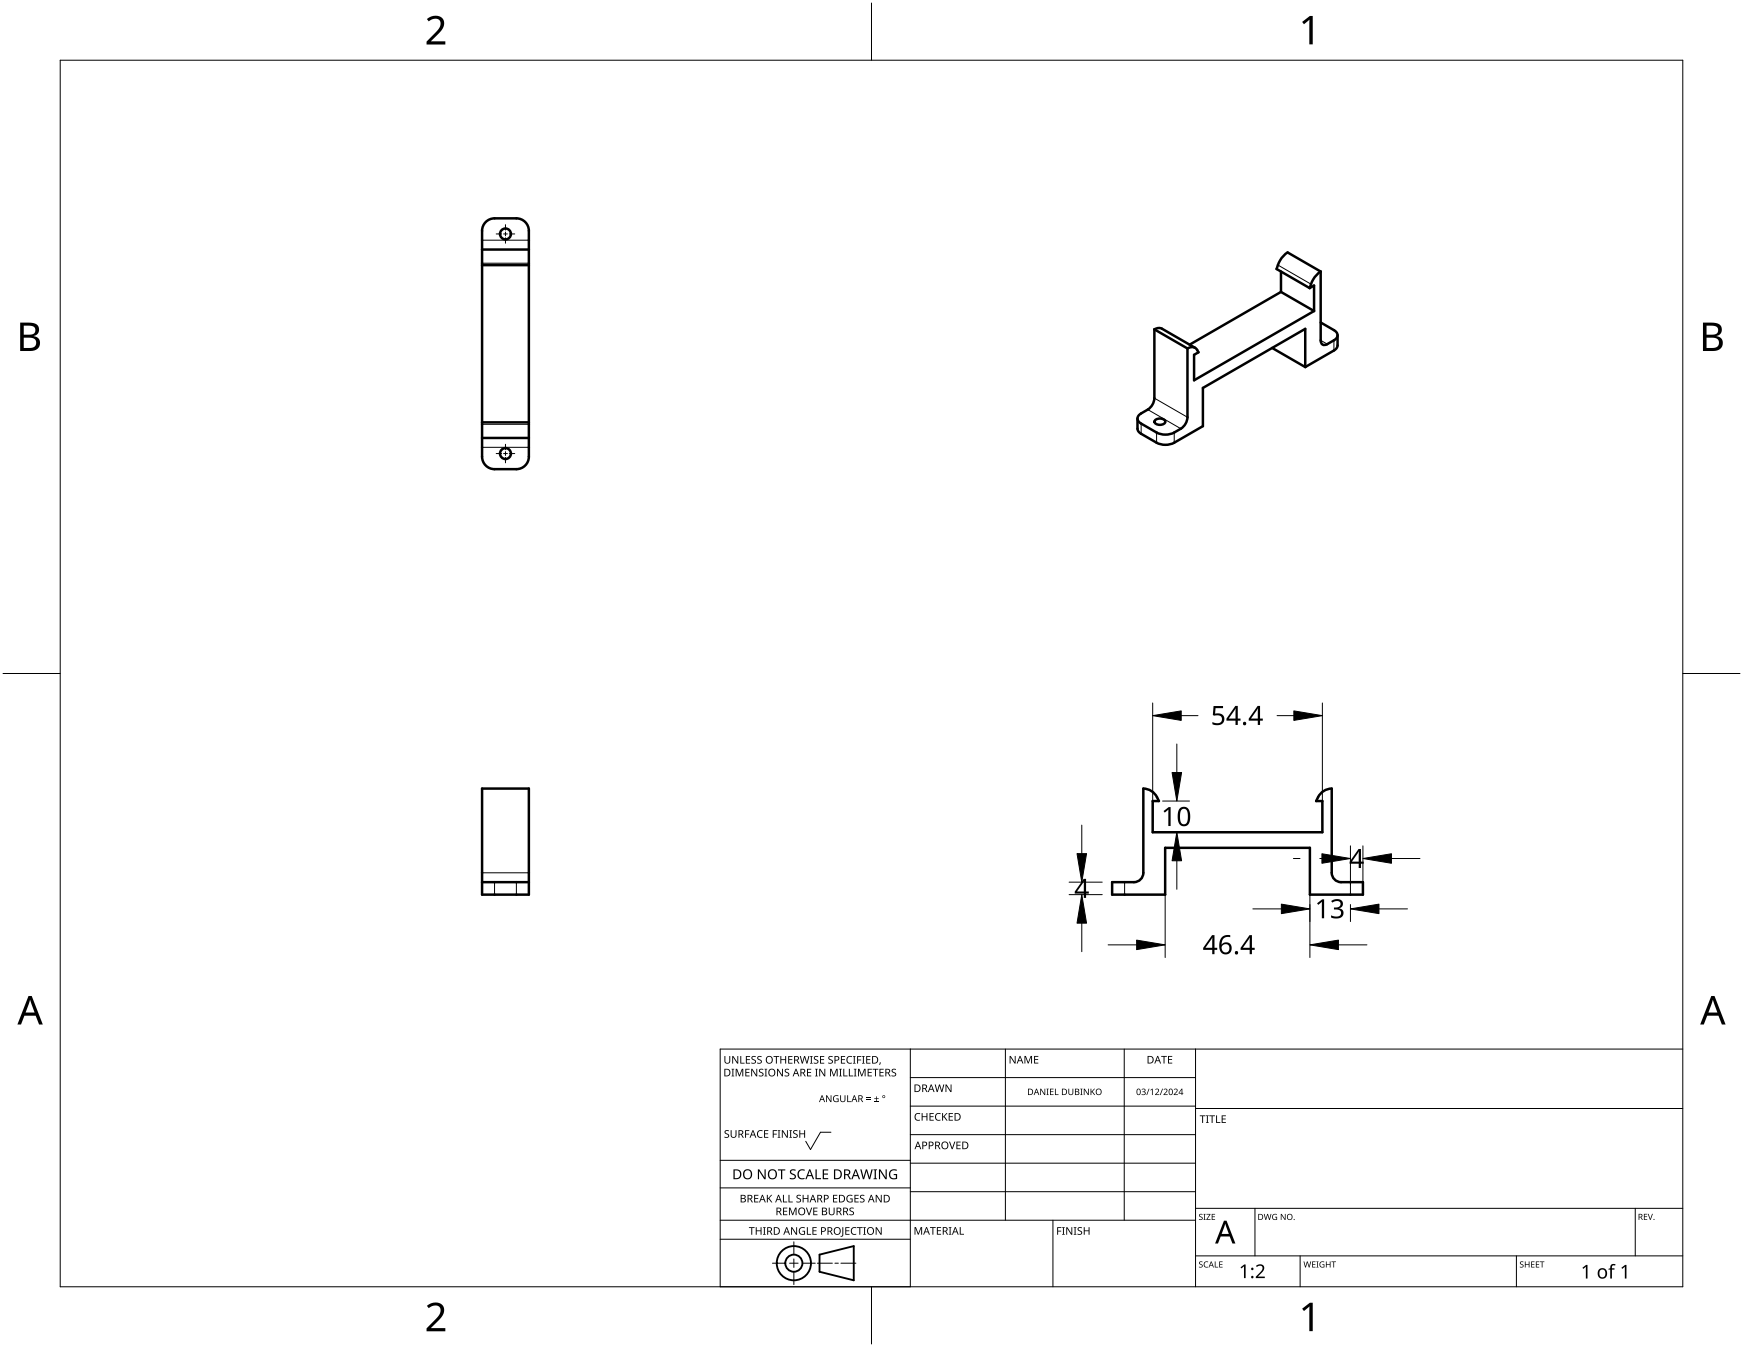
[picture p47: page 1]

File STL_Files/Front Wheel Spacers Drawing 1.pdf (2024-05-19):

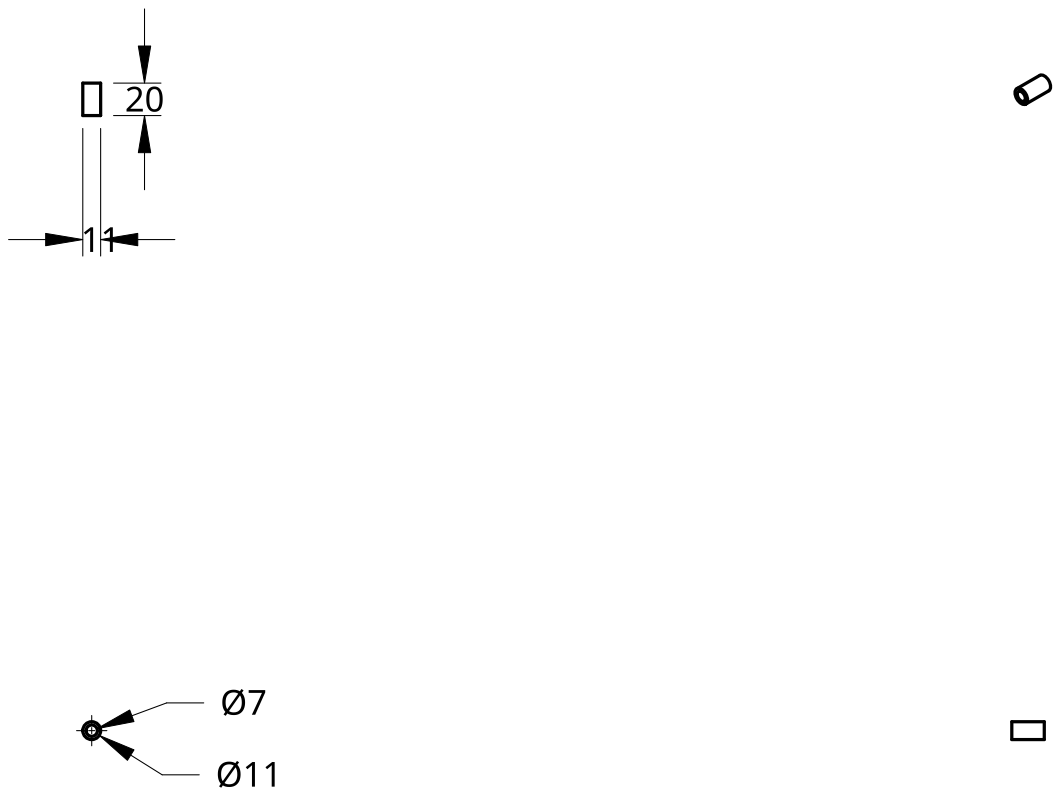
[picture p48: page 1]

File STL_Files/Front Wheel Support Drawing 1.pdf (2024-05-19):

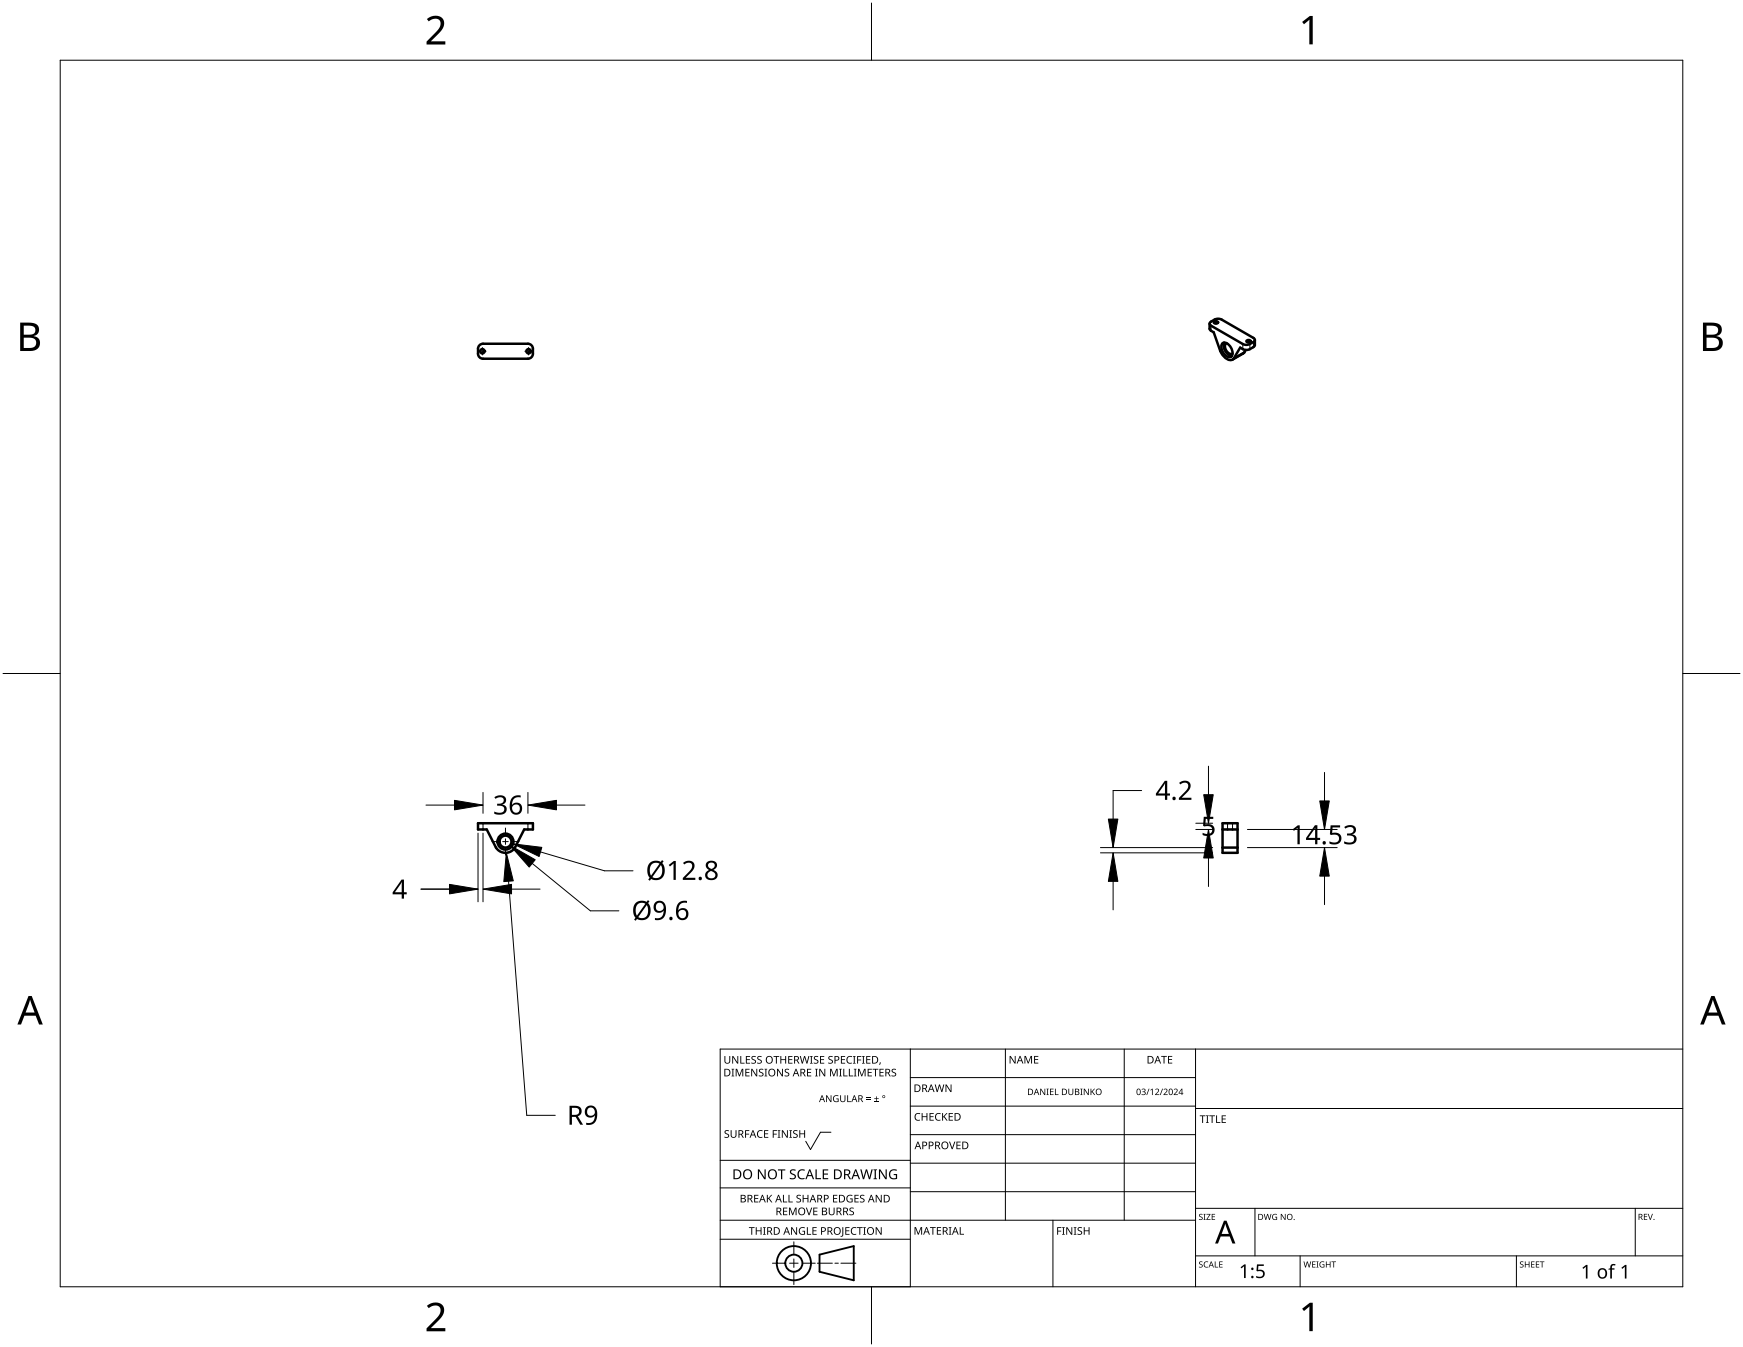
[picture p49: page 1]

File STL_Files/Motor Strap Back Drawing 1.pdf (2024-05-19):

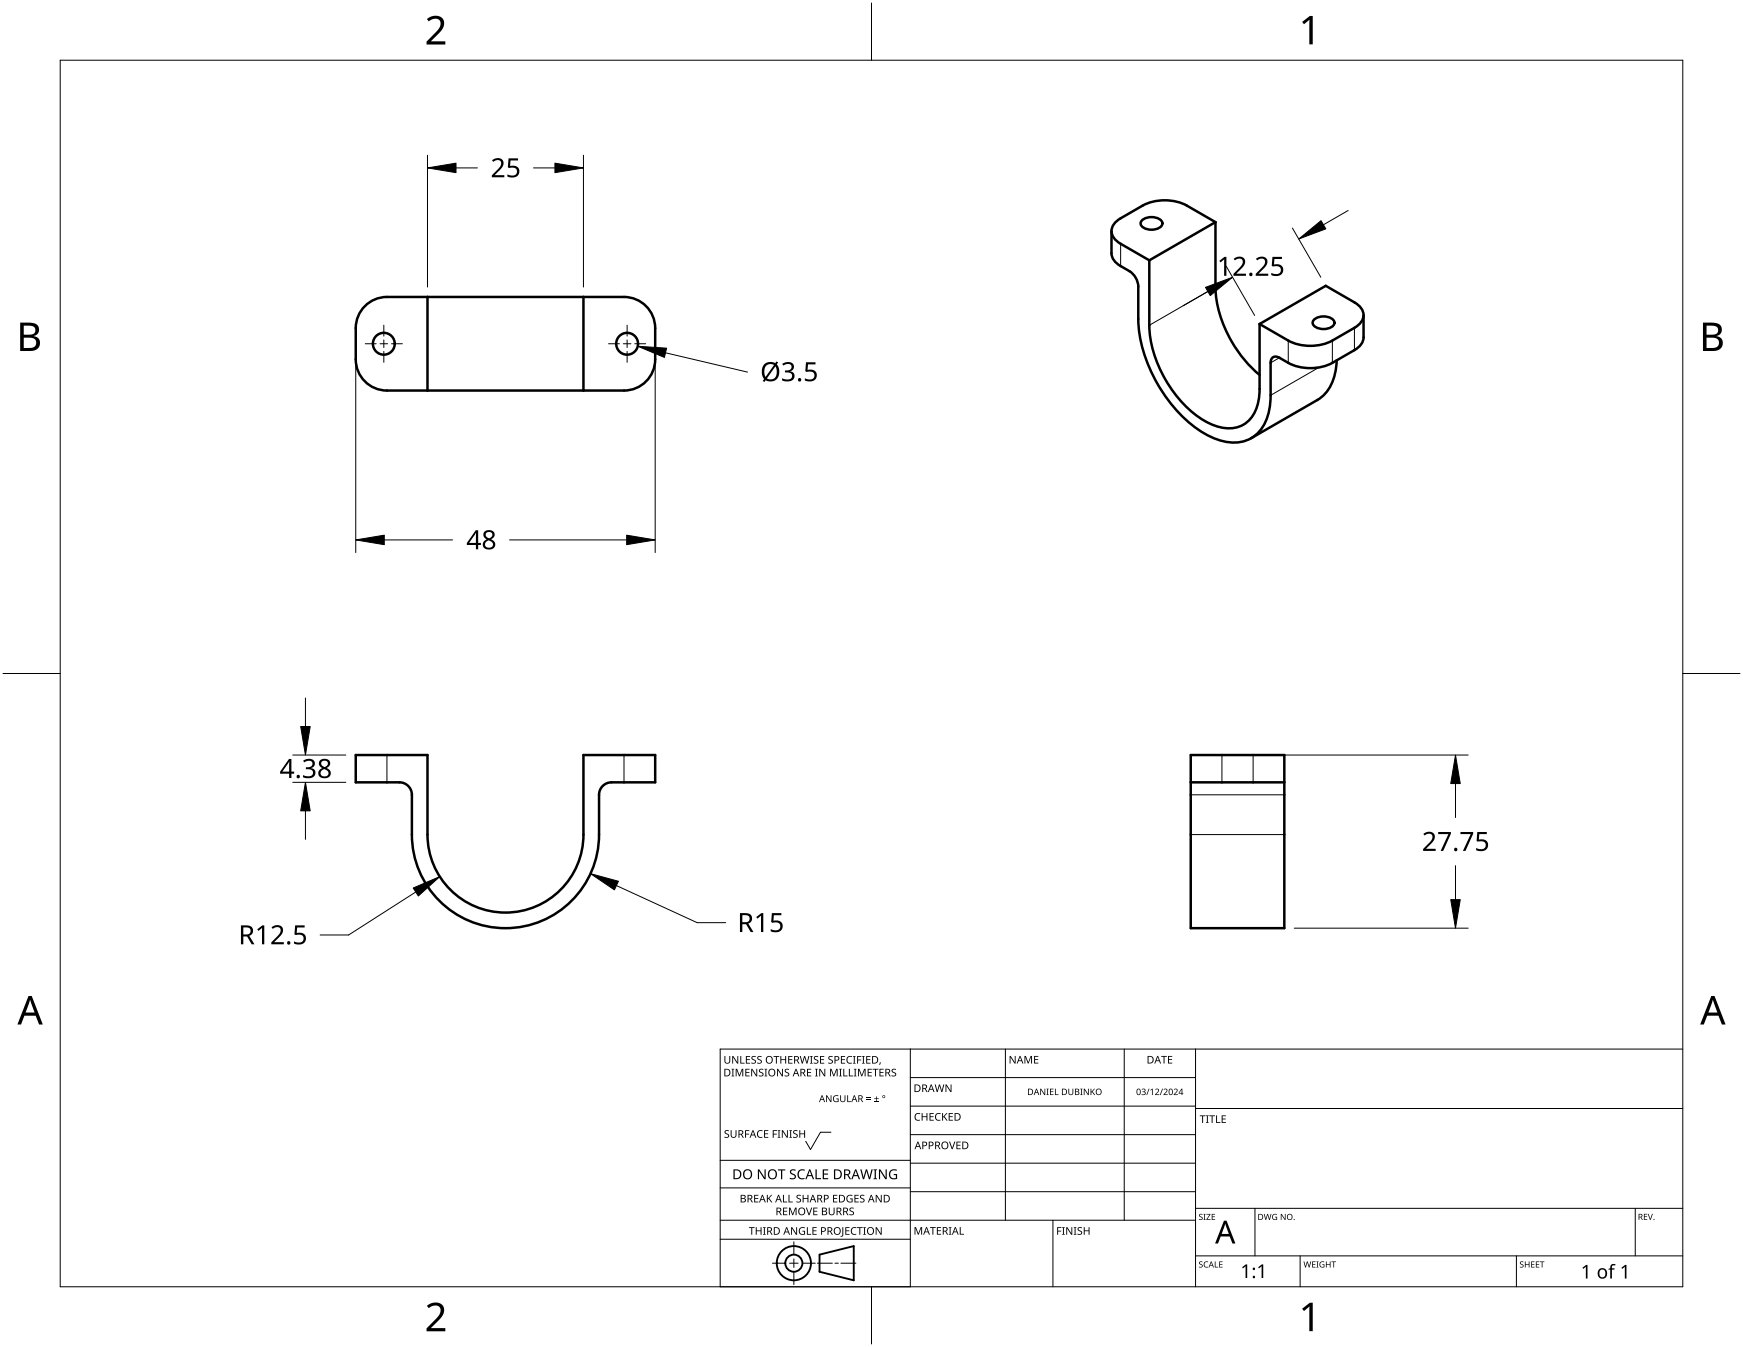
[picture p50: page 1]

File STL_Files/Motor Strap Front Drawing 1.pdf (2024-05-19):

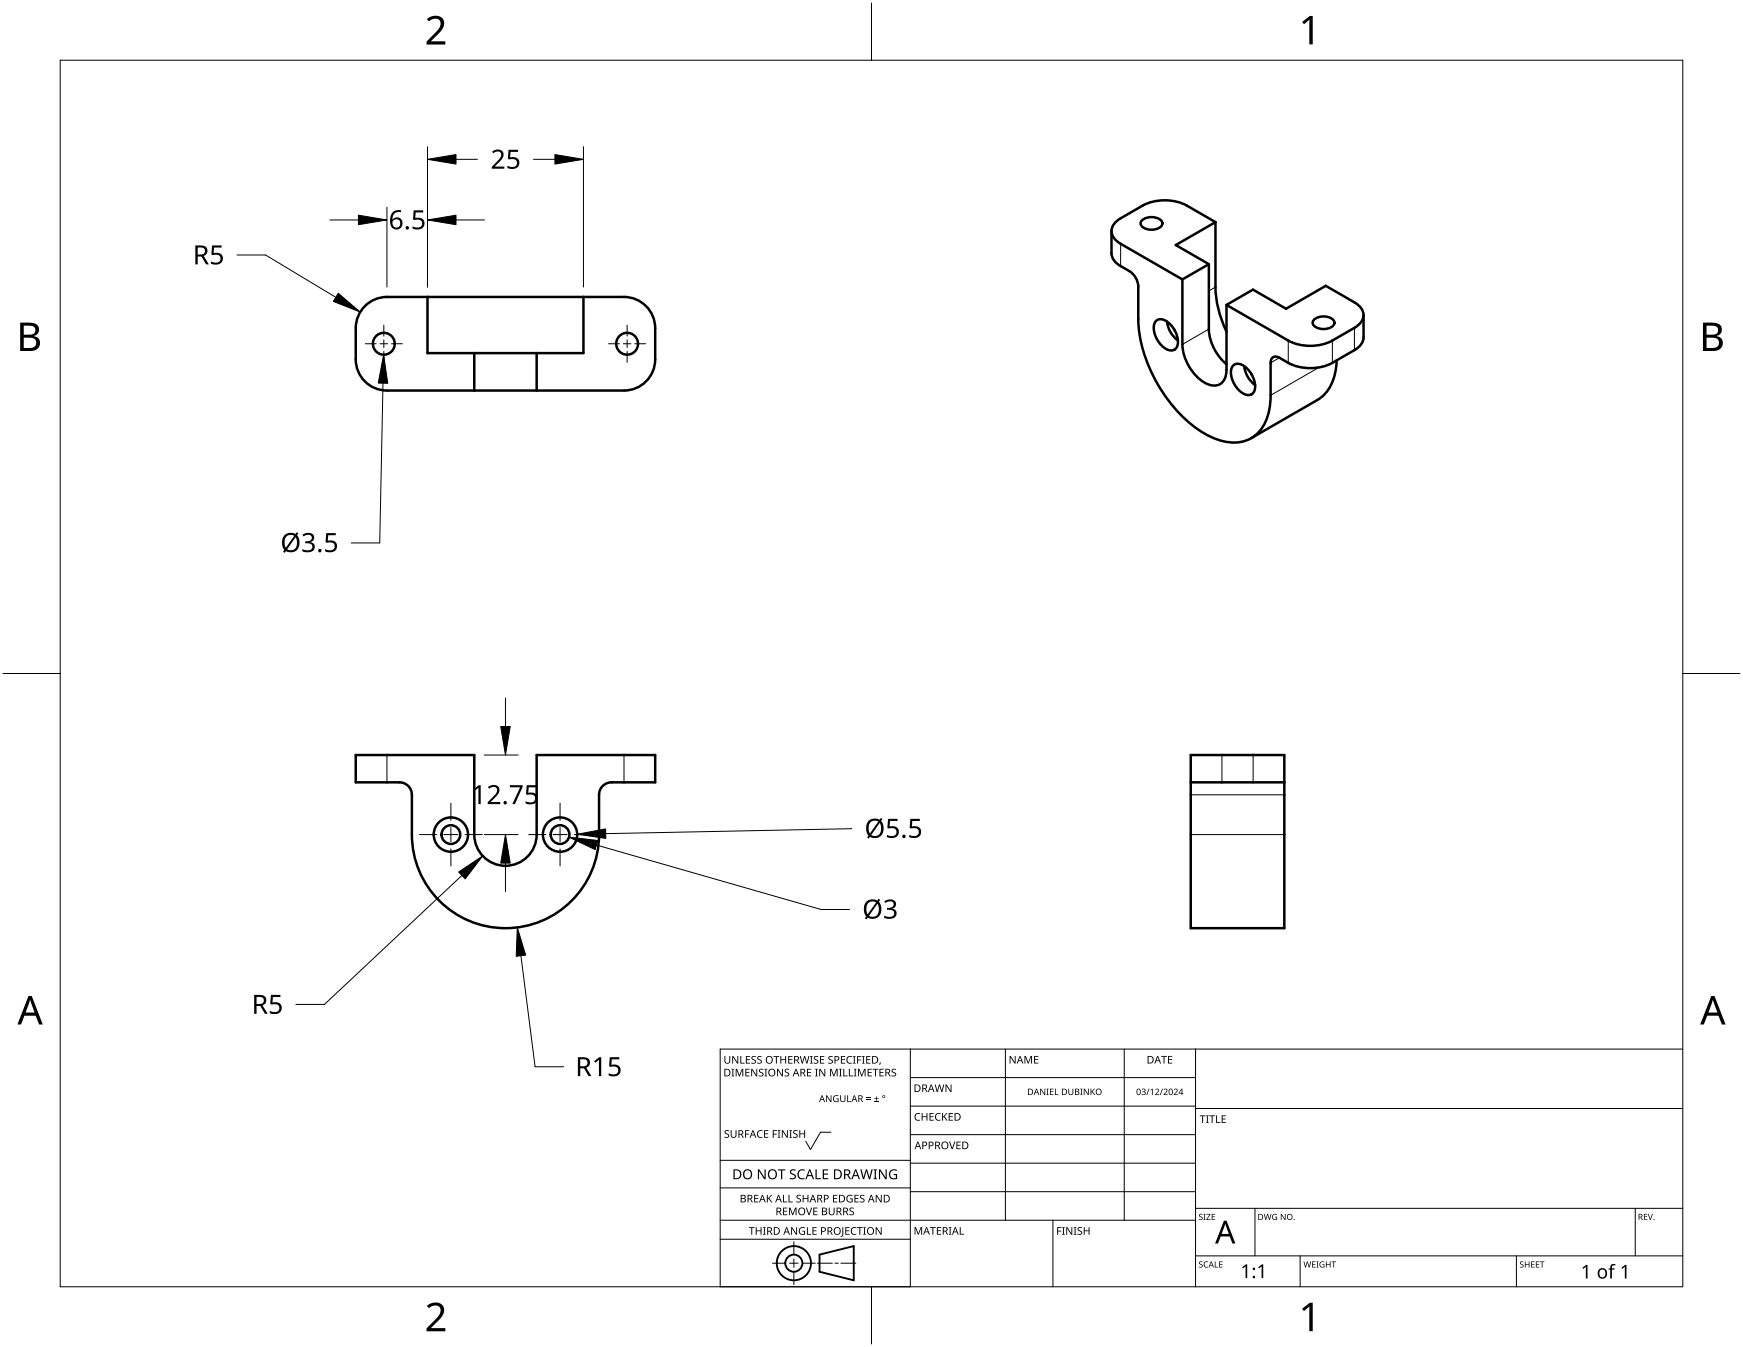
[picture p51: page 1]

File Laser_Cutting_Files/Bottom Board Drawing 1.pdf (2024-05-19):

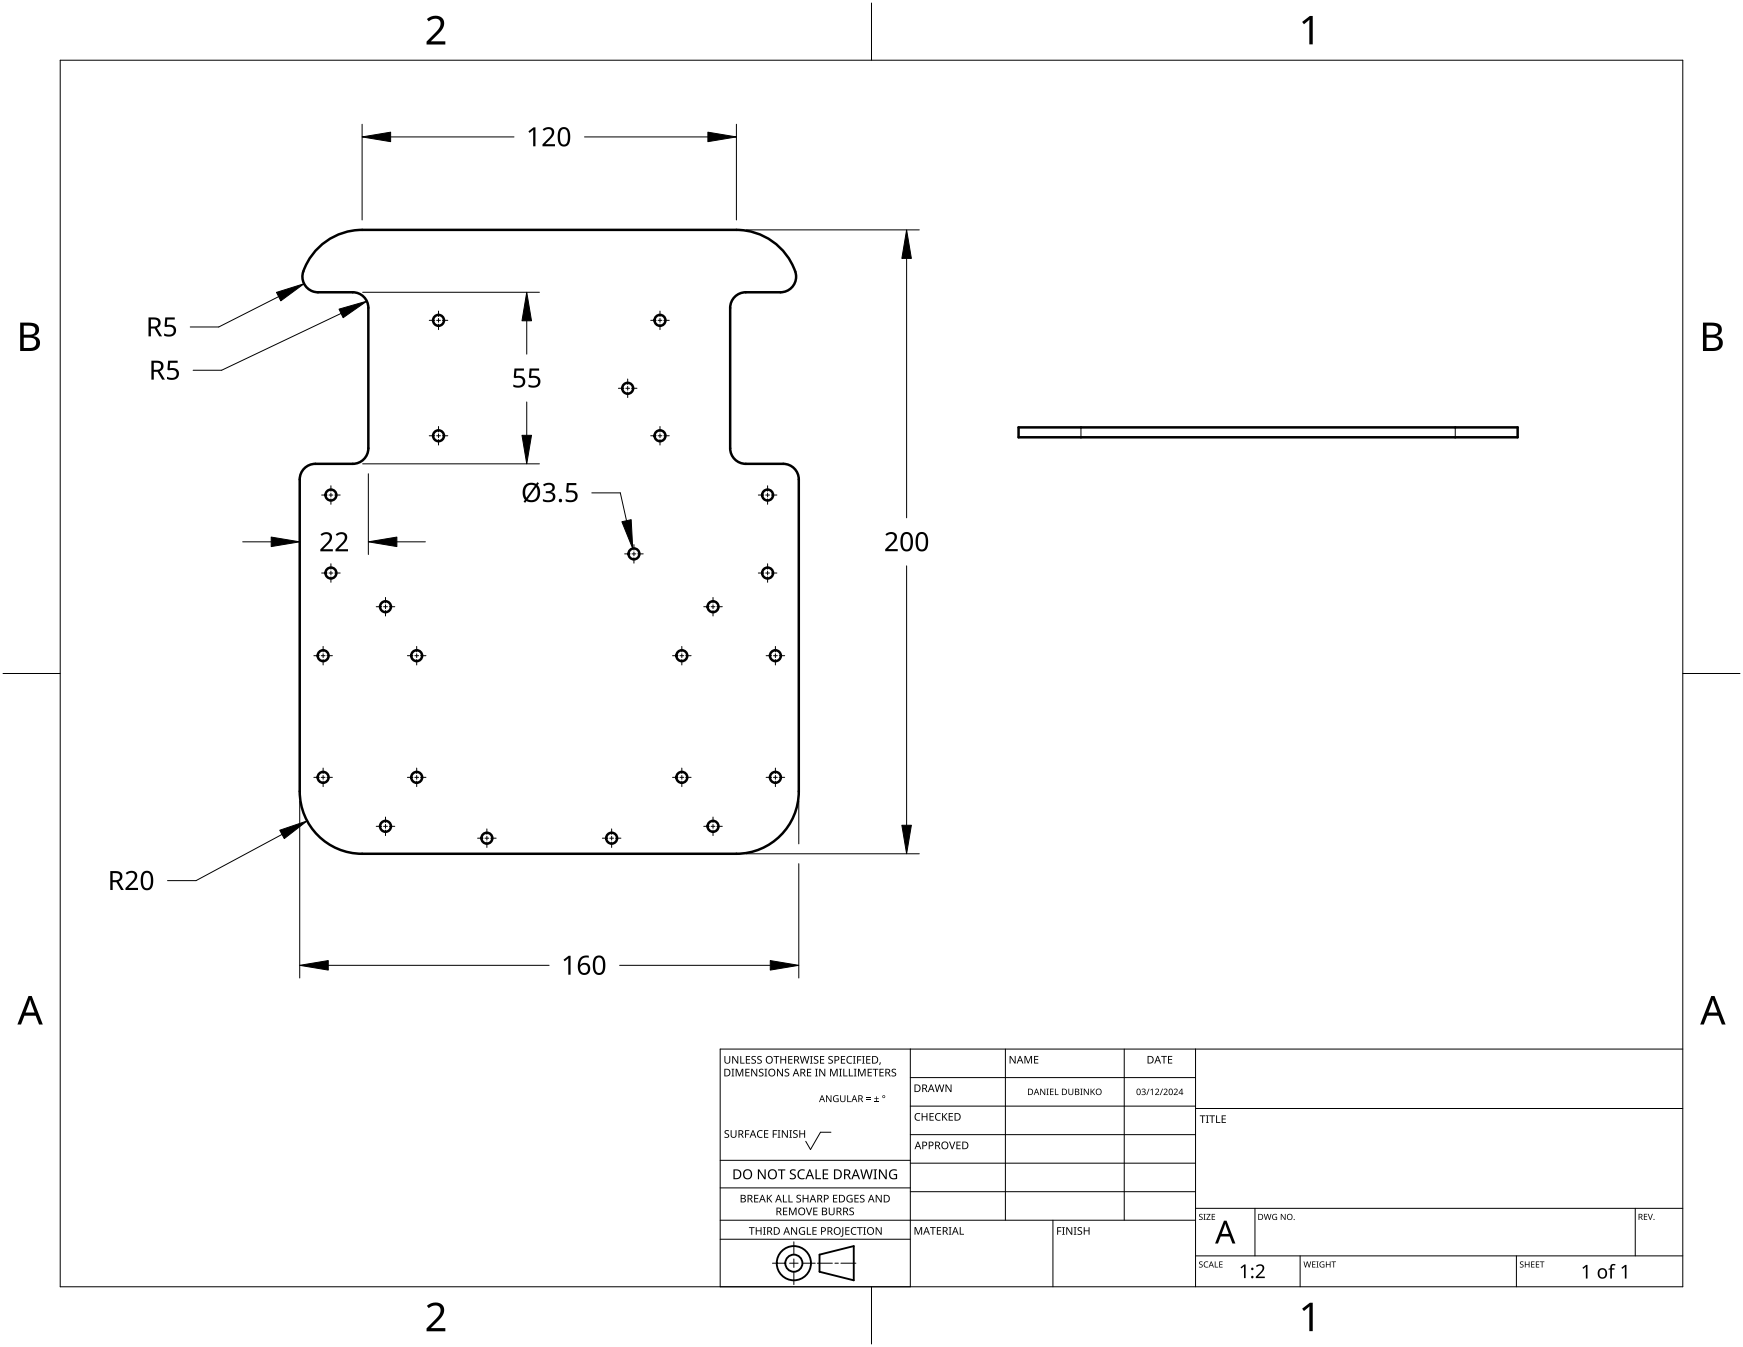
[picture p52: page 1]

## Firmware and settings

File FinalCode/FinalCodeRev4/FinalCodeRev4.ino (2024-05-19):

// MREN 303 Pico W Wifi Gamepad Read and Switch Modes
// Written For MREN 303

#include <WiFi.h>
#include <WiFiUdp.h>
#include <Servo.h>
#include <Wire.h>
#include <SparkFun_TB6612.h>

Servo servo1;
Servo servo2;
Servo servo3;

// #ifndef STASSID
// #define STASSID "Rebellious Amish Family"
// #define STAPSK "jebediah"
// #endif

#ifndef STASSID
#define STASSID "MREN303_wifi"
#define STAPSK "MREN@303p1"
#endif

//Servos
#define servo1Pin 0
#define servo2Pin 1
#define servo3Pin 2

int servo1Max;
int servo2Max;
int servo3Max;

int servo1Min;
int servo2Min;
int servo3Min;

int servo1Delay;
int servo2Delay;
int servo3Delay;

//DC Motors
#define AIN1 13
#define AIN2 14
#define PWMA 15

#define BIN1 18
#define BIN2 17
#define PWMB 16

#define STBY 19

const int offsetA = 1;
const int offsetB = 1;

Motor motor1 = Motor(AIN1, AIN2, PWMA, offsetA, STBY);  // Left motor
Motor motor2 = Motor(BIN1, BIN2, PWMB, offsetB, STBY);  // Roght motor


unsigned int localPort = 8888;  // local port to listen on

// buffers for receiving and sending data
char packetBuffer[UDP_TX_PACKET_MAX_SIZE + 1];  // buffer to hold incoming packet,
char ReplyBuffer[] = "acknowledged\r\n";        // a string to send back
// char Arrays to match commands from gamepad
char stringA[17] = "A1";
char stringA2[17] = "A0";
char stringB[17] = "B1";
char stringB2[17] = "B0";
char stringY[17] = "Y1";
char stringY2[17] = "Y0";
char stringX[17] = "X1";
char stringX2[17] = "X0";
char stringLB[17] = "LB1";
char stringLB2[18] = "LB0";
char stringRB[17] = "RB1";
char stringRB2[18] = "RB0";
char stringLS[17] = "LS1";
char stringLS2[17] = "LS0";
char stringRS[17] = "RS1";
char stringRS2[17] = "RS0";
char stringBack[17] = "Back1";
char stringBack2[17] = "Back0";
char stringStart[17] = "Strt1";
char stringStart2[17] = "Strt0";
char stringUp[17] = "Udp1";
char stringUp2[17] = "Udp0";
char stringDown[17] = "Ddp1";
char stringDown2[18] = "Ddp0";
char stringLeft[17] = "Ldp1";
char stringLeft2[18] = "Ldp0";
char stringRight[17] = "Rdp1";
char stringRight2[19] = "Rdp0";
char stringLX[17] = "L Stick X Value";
char stringLY[17] = "L Stick Y Value ";
char stringRX[17] = "R Stick X Value ";
char stringRY[17] = "R Stick Y Value ";
char stringLT[17] = "L Trigger Value ";
char stringRT[17] = "R Trigger Value ";

int valueLt = 0;
int valueRt = 0;

// SERVO VARIABLES ------------------------------------
int servo1Value = 0;
int servo2Value = 0;
int servo3Value = 0;

bool ledOn = false;

bool APressed = false;
bool BPressed = false;

bool lbPressed = false;
bool rbPressed = false;

bool ltPressed = false;
bool rtPressed = false;

bool XPressed = false;
bool YPressed = false;
// ----------------------------------------------------

// MOTOR VARIABLES ------------------------------------
int valueLx = 0;
int valueLy = 0;
int valueRx = 0;
int valueRy = 0;
// ----------------------------------------------------

//game modes
const int IDLE_MODE = 0;
const int AUTO_MODE = 1;
const int MANUAL_MODE = 2;
int current_mode = IDLE_MODE;  // Variable to store the current mode. Starts in idle mode
int manualModePrint = 0;
int idleModePrint = 0;
int autoModePrint = 0;

unsigned long startTime = 0;    // Variable to store the start time
unsigned long currentTime = 0;  // Variable to store the current time

WiFiUDP Udp;

//LT and RT to controll Servo 
void updateServoWithTriggers() {
    int servoSpeed = 0; // This will control how much to move the servo

    // Assume valueRt and valueLt range is 0 to 255
    if (valueRt > 0) { // RT pressed
        servoSpeed = map(valueRt, 0, 255, 0, 1); // Map RT value to servo speed range, e.g., 0 to 10
        servo3Value -= servoSpeed; // Increase servo position
    } 
    if (valueLt > 0) { // LT pressed
        servoSpeed = map(valueLt, 0, 255, 0, 1); // Map LT value to servo speed range
        servo3Value += servoSpeed; // Decrease servo position
    }

    // Constrain servo1Value to prevent it from going beyond the limits
    servo3Value = constrain(servo3Value, servo3Min, servo3Max);

    // Write the new servo position
    servo3.write(servo1Value);
}

void setup() {  //This handles network function and runs on core 1
  Serial.begin(9600);
  WiFi.begin(STASSID, STAPSK);
  while (WiFi.status() != WL_CONNECTED) {
    Serial.print('.');
    delay(500);
  }
  Serial.print("Connected! IP address: ");
  Serial.println(WiFi.localIP());
  Serial.printf("UDP server on port %d\n", localPort);
  Udp.begin(localPort);
}
void setup1() {  //This handles all inputs and outputs and runs on core 2

  pinMode(LED_BUILTIN, OUTPUT);
  digitalWrite(LED_BUILTIN, 0);

  // Initialize motor driver pins as outputs
  pinMode(STBY, OUTPUT);
  pinMode(AIN1, OUTPUT);
  pinMode(AIN2, OUTPUT);
  pinMode(PWMA, OUTPUT);
  pinMode(BIN1, OUTPUT);
  pinMode(BIN2, OUTPUT);
  pinMode(PWMB, OUTPUT);

  // Servo Setup
  servo1.attach(servo1Pin, 600, 2500);
  servo2.attach(servo2Pin, 600, 2500);
  servo3.attach(servo3Pin, 600, 2500);

  //Initial Servo Positions
  servo1Value = 90;
  servo1Max = 180;
  servo1Min = 35;
  servo1Delay = 15;
  servo1.write(servo1Value);  //servo doesnt work

  servo2Value = 60;
  servo2Max = 130;
  servo2Min = 0;
  servo2Delay = 15;
  servo2.write(servo2Value);  // works well

  servo3Value = 0;
  servo3Max = 180;
  servo3Min = 0;
  servo3Delay = 15;
  servo3.write(servo3Value);
}

void loop() {  //This loop executes on Core 1 of the Pico, handles networking and recieves commands
  // if there's data available, read a packet
  int packetSize = Udp.parsePacket();
  if (packetSize) {
    Serial.printf("Received packet of size %d from %s:%d\n    (to %s:%d)\n", packetSize, Udp.remoteIP().toString().c_str(), Udp.remotePort(), Udp.destinationIP().toString().c_str(), Udp.localPort());

    // read the packet into packetBufffer
    int n = Udp.read(packetBuffer, UDP_TX_PACKET_MAX_SIZE);
    packetBuffer[n] = 0;

    char comparisonString[17] = "";
    char valueString[5] = "";

    for (int i = 0; i < 16; i++) {
      comparisonString[i] = packetBuffer[i];
    }
    comparisonString[16] = 0;

    Serial.println("Comp String:");
    Serial.println(comparisonString);

    // Mode Switching Buttons
    if (strcmp(comparisonString, stringStart) == 0) {
      if (current_mode == IDLE_MODE) {           // You can only go to auto mode from idle mode
        Serial.println("Setting mode to auto");  //this line may be removed for final version
        current_mode = AUTO_MODE;                // Change to auto mode
        startTime = millis();                    // Start recording the time
      }
    }
    if (strcmp(comparisonString, stringBack) == 0) {
      Serial.println("Setting mode to manual");  //this line may be removed for final version
      current_mode = MANUAL_MODE;                // Change to manual mode
    }
    if (strcmp(comparisonString, stringRS) == 0) {
      Serial.println("Setting mode to idle");  //this line may be removed for final version
      current_mode = IDLE_MODE;                // Change to idle mode
    }



    if (strcmp(comparisonString, stringLX) == 0) {
      for (int i = 16; i <= packetSize; i++) {
        valueString[(i - 16)] = packetBuffer[i];
      }
      valueString[5] = 0;
      valueLx = atoi(valueString);
      Serial.println("LX Value is:");
      Serial.println(valueLx);
    }
    if (strcmp(comparisonString, stringLY) == 0) {
      for (int i = 16; i <= packetSize; i++) {
        valueString[(i - 16)] = packetBuffer[i];
      }
      valueString[5] = 0;
      valueLy = atoi(valueString);
      Serial.println("LY Value is:");
      Serial.println(valueLy);
    }
    if (strcmp(comparisonString, stringRX) == 0) {
      for (int i = 16; i <= packetSize; i++) {
        valueString[(i - 16)] = packetBuffer[i];
      }
      valueString[5] = 0;
      valueRx = atoi(valueString);
      Serial.println("RX Value is:");
      Serial.println(valueRx);
    }
    if (strcmp(comparisonString, stringRY) == 0) {
      for (int i = 16; i <= packetSize; i++) {
        valueString[(i - 16)] = packetBuffer[i];
      }
      valueString[5] = 0;
      valueRy = atoi(valueString);
      Serial.println("RY Value is:");
      Serial.println(valueRy);
    }
    if (strcmp(comparisonString, stringRT) == 0) {
      for (int i = 16; i <= packetSize; i++) {
        valueString[(i - 16)] = packetBuffer[i];
      }
      valueString[5] = 0;
      valueRt = atoi(valueString);
      Serial.println("RT Value is:");
      Serial.println(valueRt);
    }
    if (strcmp(comparisonString, stringLT) == 0) {
      for (int i = 16; i <= packetSize; i++) {
        valueString[(i - 16)] = packetBuffer[i];
      }
      valueString[5] = 0;
      valueLt = atoi(valueString);
      Serial.println("LT Value is:");
      Serial.println(valueLt);
    }

    // Servo Button Logic
    //Servo 1 Logic
    if (strcmp(comparisonString, stringA) == 0) {
      APressed = true;
      BPressed = false;  // Ensure LB is not pressed
    } else if (strcmp(comparisonString, stringB) == 0) {
      BPressed = true;
      APressed = false;  // Ensure RB is not pressed
    } else if (strcmp(comparisonString, stringA2) == 0) {
      APressed = false;
    } else if (strcmp(comparisonString, stringB2) == 0) {
      BPressed = false;
    }

    // //Servo 2 Logic
    if (strcmp(comparisonString, stringRB) == 0) {
      rbPressed = true;
      lbPressed = false;  // Ensure LB is not pressed
    } else if (strcmp(comparisonString, stringLB) == 0) {
      lbPressed = true;
      rbPressed = false;  // Ensure RB is not pressed
    } else if (strcmp(comparisonString, stringRB2) == 0) {
      rbPressed = false;
    } else if (strcmp(comparisonString, stringLB2) == 0) {
      lbPressed = false;
    }

//Servo 3
    if (strcmp(comparisonString, stringY) == 0) {
      YPressed = true;
      XPressed = false;  // Ensure LB is not pressed
    } else if (strcmp(comparisonString, stringX) == 0) {
      XPressed = true;
      YPressed = false;  // Ensure RB is not pressed
    } else if (strcmp(comparisonString, stringY2) == 0) {
      YPressed = false;
    } else if (strcmp(comparisonString, stringX2) == 0) {
      XPressed = false;
    }
    //---------------------------------------------------------

    // send a reply, to the IP address and port that sent us the packet we received
    Udp.beginPacket(Udp.remoteIP(), Udp.remotePort());
    Udp.write(ReplyBuffer);
    Udp.endPacket();
  }
}

void loop1() {  //This Runs on Core 2 and performs all inputs and outputs

  currentTime = millis();

  // After spending more than 30 s in auto mode:
  // if ((current_mode == AUTO_MODE) && (currentTime - startTime) >= 30000) {
  //   Serial.println("TIME OUT: changing to manual mode");  //this line may be removed for final version
  //   current_mode = MANUAL_MODE;                           // Change to manual mode
  // }
  studentCode(current_mode);
}

// YOUR CODING GOES HERE
void studentCode(int current_mode) {
  if (current_mode == IDLE_MODE) {
    if (idleModePrint == 0) {
      Serial.println("You are in idle mode");
      idleModePrint = 1;
    }
    digitalWrite(LED_BUILTIN, LOW);  // LED is off for idle mode
                                     // Initialize motors state as off
    digitalWrite(STBY, HIGH);
    digitalWrite(AIN1, LOW);
    digitalWrite(AIN2, LOW);
    digitalWrite(PWMA, HIGH);
    digitalWrite(BIN1, LOW);
    digitalWrite(BIN2, LOW);
    digitalWrite(PWMB, HIGH);
    // No further action required
  } else if (current_mode == AUTO_MODE) {
    if (autoModePrint == 0) {
      Serial.println("You are in auto mode");
      autoModePrint = 1;
    }
    digitalWrite(LED_BUILTIN, LOW);

  }

  else if (current_mode == MANUAL_MODE) {
    if (manualModePrint == 0) {
      Serial.println("You are in manual mode");
      manualModePrint = 1;
    }
    //this line may be removed for final version
    digitalWrite(LED_BUILTIN, HIGH);  // LED is on for manual mode

    //-----------------------------------------------------------------------

    // MOTOR CODE START  -------------------------------------------------------
    int speedLeft = 0;
    int speedRight = 0;

    // Turning
    if (valueRx > 0) {
      // Right
      //speedLeft += map(valueRx, 0, 255, 0, 255);
      speedLeft += valueRx;
      speedRight -= map(valueRx, 0, 255, 0, 255);
    } else if (valueRx < 0) {
      // Left
      int mappedValue = map(-valueRx, 0, 255, 0, 255);
      speedLeft -= mappedValue;
      speedRight += mappedValue;
    }

    // Driving
    if (valueLy > 0) {
      // Forward
      int speedFwd = map(valueLy, 0, 255, 0, 255);
      speedLeft += speedFwd;
      speedRight += speedFwd;
    } else if (valueLy < 0) {
      // Backward
      int speedBck = map(-valueLy, 0, 255, 0, 255);
      speedLeft -= speedBck;
      speedRight -= speedBck;
    }

    // Ensure speeds are within motor limits
    speedLeft = constrain(speedLeft, -255, 255);
    speedRight = constrain(speedRight, -255, 255);

    // Drive motors
    motor1.drive(speedLeft);
    motor2.drive(speedRight);
    // MOTOR CODE END  ---------------------------------------------------------

    // SERVO CODE START --------------------------------------------------------------
    // Servo 1 Logic (GRIPPER)
    if (BPressed) {
      servo1Value++;
      delay(servo1Delay);
      if (servo1Value > servo1Max) {
        servo1Value = servo1Max;  // limit to max
      }
      Serial.print("servo1Value: ");
      Serial.println(servo1Value);

    } else if (APressed) {
      servo1Value--;
      delay(servo1Delay);

      if (servo1Value < servo1Min) {
        servo1Value = servo1Min;  // limit to max
      }
      Serial.print("servo1Value: ");
      Serial.println(servo1Value);
    }
    servo1.write(servo1Value);

    // Servo 2 Logic (SCOOP)
    if (rbPressed) {
      servo2Value++;
      delay(servo2Delay);

      if (servo2Value > servo2Max) {
        servo2Value = servo2Max;  // limit to max
      }
      Serial.print("servo2Value: ");
      Serial.println(servo2Value);
    } else if (lbPressed) {
      servo2Value--;
      delay(servo2Delay);

      if (servo2Value < servo2Min) {
        servo2Value = servo2Min;  // limit to max
      }
      Serial.print("servo2Value: ");
      Serial.println(servo2Value);
    }
    servo2.write(servo2Value);

    // Servo 3 Logic (CRANE)
    updateServoWithTriggers();
    // if (XPressed) {
    //   servo3Value++;
    //   delay(servo3Delay);

    //   if (servo3Value > servo3Max) {
    //     servo3Value = servo3Max;  // limit to max
    //   }
    //   Serial.print("servo3Value: ");
    //   Serial.println(servo3Value);
    // } else if (YPressed) {
    //   servo3Value--;
    //   delay(servo3Delay);

    //   if (servo3Value < servo3Min) {
    //     servo3Value = servo3Min;  // limit to max
    //   }
    //   Serial.print("servo3Value: ");
    //   Serial.println(servo3Value);
    // }
    servo3.write(servo3Value);
  }
  return;
}

void autonomousMode() {
}

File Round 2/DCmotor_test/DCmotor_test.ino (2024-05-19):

#define AIN1 13
#define AIN2 14
#define PWMA 15

#define BIN1 18
#define BIN2 17
#define PWMB 16

#define motor1EncoderA 11
#define motor1EncoderB 12
#define STBY 19

#include <SparkFun_TB6612.h>

const int offsetA = 1;
const int offsetB = 1;

Motor motor1 = Motor(AIN1, AIN2, PWMA, offsetA, STBY);
Motor motor2 = Motor(BIN1, BIN2, PWMB, offsetB, STBY);

void setup(){
}

void loop()
{
   //Use of the drive function which takes as arguements the speed
   //and optional duration.  A negative speed will cause it to go
   //backwards.  Speed can be from -255 to 255.  Also use of the 
   //brake function which takes no arguements.
   motor1.drive(255,3000);
   motor1.brake();
      delay(1000);
   motor1.drive(-255,3000);
   motor1.brake();
      delay(1000);

   motor2.drive(255,3000);
   motor2.brake();
      delay(1000);
   motor2.drive(-255,3000);
   motor2.brake();
      delay(1000);
   //Use of the drive function which takes as arguements the speed
   //and optional duration.  A negative speed will cause it to go
   //backwards.  Speed can be from -255 to 255.  Also use of the 
   //brake function which takes no arguements.
   
//   motor2.drive(255,1000);
//   motor2.drive(-255,1000);
//   motor2.brake();
//   delay(1000);

   //Use of the forward function, which takes as arguements two motors
   //and optionally a speed.  If a negative number is used for speed
   //it will go backwards
   
//   forward(motor1, motor2, 150);
//   delay(1000);

   //Use of the back function, which takes as arguments two motors 
   //and optionally a speed.  Either a positive number or a negative
   //number for speed will cause it to go backwards
//   back(motor1, motor2, -150);
//   delay(1000);

   //Use of the brake function which takes as arguments two motors.
   //Note that functions do not stop motors on their own.
//   brake(motor1, motor2);
//   delay(1000);

   //Use of the left and right functions which take as arguements two
   //motors and a speed.  This function turns both motors to move in 
   //the appropriate direction.  For turning a single motor use drive.
//   left(motor1, motor2, 100);
//   delay(1000);
//   right(motor1, motor2, 100);
//   delay(1000);
//
//   //Use of brake again.
//   brake(motor1, motor2);
//   delay(1000);
}
